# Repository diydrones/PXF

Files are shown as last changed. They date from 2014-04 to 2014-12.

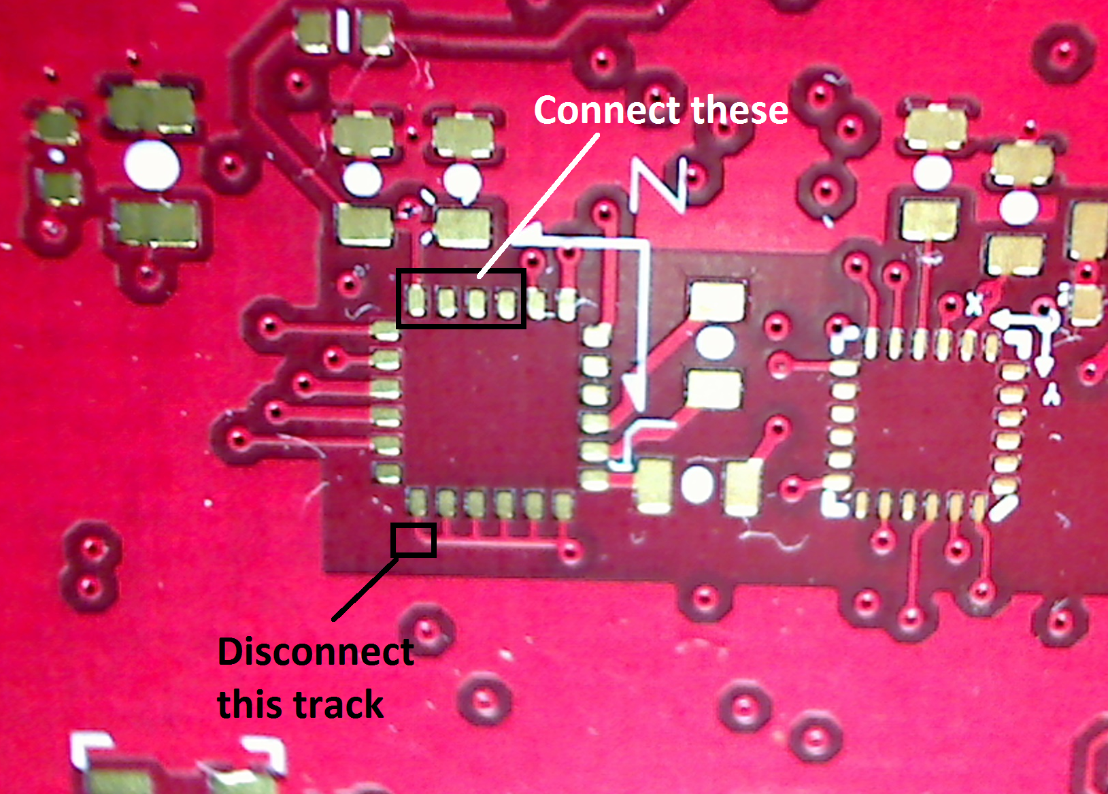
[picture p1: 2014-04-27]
v1.0 errata/LSM.png

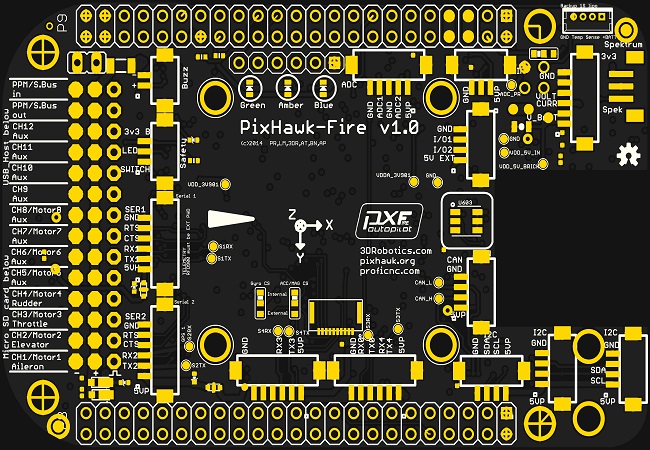
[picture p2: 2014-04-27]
CapeRegistration/PixHawk_Fire_v1.0_board_top.jpg

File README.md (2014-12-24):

PXF ( current boards are 1.4)
===


This is the new Repository for the PXF Linux AutoPilot. 

this Project will alow the porting of ArduPilot to Linux, allowing us to add a multitude of other features to the Autopilot.

The actual Autopilot code will still be in the ArduPilot repo.<a href="https://github.com/diydrones/ardupilot" title="https://github.com/diydrones/ardupilot" target="https://github.com/diydrones/ardupilot"> https://github.com/diydrones/ardupilot</a>

This Repo will house the Hardware Schematics, Datasheets, and software specific to the PXF project.

Version 1 of this project is a cape for the BBB.

This project is for developers, it will NOT be supported by the DIYDrones or Ardupilot support forums for general users. 

This means we do not expect that this board will be plug and play, nor do we intend it to be.

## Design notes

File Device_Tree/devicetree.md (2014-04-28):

Each cape for the BeagleBone Black has it's own **device tree fragment** as a overlay to the existing device tree.   
The **lib/firmware** consists of all the possible *overlays*

```
am335x-pm-firmware.bin		    BB-BONE-BACON-00A0.dtbo	BB-I2C1A1-00A0.dtbo	  cape-bone-2g-emmc1.dtbo	    libertas_cs_helper.fw
am33xx_pwm-00A0.dtbo		    BB-BONE-BACONE-00A0.dtbo	BB-SPIDEV0-00A0.dtbo	  cape-bone-adafruit-lcd-00A0.dtbo  LICENCE.atheros_firmware
atmel_at76c502_3com.bin		    BB-BONE-BACONE2-00A0.dtbo	BB-SPIDEV1-00A0.dtbo	  cape-boneblack-hdmi-00A0.dtbo     LICENCE.broadcom_bcm43xx
atmel_at76c502_3com-wpa.bin	    BB-BONE-CAM3-01-00A2.dtbo	BB-SPIDEV1A1-00A0.dtbo	  cape-boneblack-hdmin-00A0.dtbo    LICENCE.rtlwifi_firmware.txt
atmel_at76c502.bin		    BB-BONE-eMMC1-01-00A0.dtbo	BB-UART1-00A0.dtbo	  cape-bone-dvi-00A0.dtbo	    LICENCE.ti-connectivity
atmel_at76c502d.bin		    BB-BONE-GPEVT-00A0.dtbo	BB-UART2-00A0.dtbo	  cape-bone-dvi-00A1.dtbo	    mwl8k
atmel_at76c502d-wpa.bin		    BB-BONE-GPS-00A0.dtbo	BB-UART4-00A0.dtbo	  cape-bone-dvi-00A2.dtbo	    rt2561.bin
atmel_at76c502e.bin		    BB-BONE-LCD4-01-00A0.dtbo	BB-UART5-00A0.dtbo	  cape-bone-exptest-00A0.dtbo	    rt2561s.bin
atmel_at76c502e-wpa.bin		    BB-BONE-LCD4-01-00A1.dtbo	bone_pwm_P8_13-00A0.dtbo  cape-bone-geiger-00A0.dtbo	    rt2661.bin
atmel_at76c502-wpa.bin		    BB-BONE-LCD7-01-00A2.dtbo	bone_pwm_P8_19-00A0.dtbo  cape-bone-hexy-00A0.dtbo	    rt2860.bin
atmel_at76c503-i3861.bin	    BB-BONE-LCD7-01-00A3.dtbo	bone_pwm_P8_34-00A0.dtbo  cape-bone-iio-00A0.dtbo	    rt2870.bin
atmel_at76c503-i3863.bin	    BB-BONE-LCD7-01-00A4.dtbo	bone_pwm_P8_36-00A0.dtbo  cape-bone-lcd3-00A0.dtbo	    rt3070.bin
atmel_at76c503-rfmd-0.90.2-140.bin  BB-BONELT-BT-00A0.dtbo	bone_pwm_P8_45-00A0.dtbo  cape-bone-lcd3-00A2.dtbo	    rt3071.bin
atmel_at76c503-rfmd-acc.bin	    BB-BONE-PRU-01-00A0.dtbo	bone_pwm_P8_46-00A0.dtbo  cape-bone-mrf24j40-00A0.dtbo	    rt3090.bin
atmel_at76c503-rfmd.bin		    BB-BONE-PRU-02-00A0.dtbo	bone_pwm_P9_14-00A0.dtbo  cape-bone-nixie-00A0.dtbo	    rt73.bin
atmel_at76c504_2958-wpa.bin	    BB-BONE-PRU-03-00A0.dtbo	bone_pwm_P9_16-00A0.dtbo  cape-bone-pinmux-test-00A0.dtbo   rtlwifi
atmel_at76c504a_2958-wpa.bin	    BB-BONE-PRU-04-00A0.dtbo	bone_pwm_P9_21-00A0.dtbo  cape-bone-replicape-00A2.dtbo     sd8385.bin
atmel_at76c504.bin		    BB-BONE-PWMT-00A0.dtbo	bone_pwm_P9_22-00A0.dtbo  cape-bone-replicape-00A3.dtbo     sd8385_helper.bin
atmel_at76c504c-wpa.bin		    BB-BONE-RS232-00A0.dtbo	bone_pwm_P9_28-00A0.dtbo  cape-bone-tester-00A0.dtbo	    sd8686.bin
atmel_at76c505a-rfmd2958.bin	    BB-BONE-RST-00A0.dtbo	bone_pwm_P9_29-00A0.dtbo  cape-bone-weather-00A0.dtbo	    sd8686_helper.bin
atmel_at76c505-rfmd2958.bin	    BB-BONE-RST2-00A0.dtbo	bone_pwm_P9_31-00A0.dtbo  carl9170-1.fw			    sd8688.bin
atmel_at76c505-rfmd.bin		    BB-BONE-RTC-00A0.dtbo	bone_pwm_P9_42-00A0.dtbo  DNIL-AMPCAPE-1-00R1.dtbo	    sd8688_helper.bin
atmel_at76c506.bin		    BB-BONE-SERL-01-00A1.dtbo	brcm			  htc_9271.fw			    ti-connectivity
atmel_at76c506-wpa.bin		    BB-BONE-SERL-03-00A1.dtbo	cape-bebopr-brdg-R2.dtbo  lbtf_usb.bin			    TT3201-001-01.dtbo
BB-ADC-00A0.dtbo		    BB-GPIOHELP-00A0.dtbo	cape-bebopr-ena-R2.dtbo   libertas			    usb8388.bin
BB-BONE-AUDI-01-00A0.dtbo	    BB-I2C1-00A0.dtbo		cape-bebopr-R2.dtbo	  libertas_cs.fw		    zd1211
```
Capemgr is used to detect installed expansion boards and load the appropriate device tree fragment at boot time.  
> A key feature of Capemgr is the ability to load Device Tree fragments as overlays to the existing Device Tree at runtime. On the BeagleBone, each cape has a Device Tree fragment which describes it.

In the beagleboard kernel, for the PixHawk Fire cape, a patch file named will have to be merged [here](https://github.com/beagleboard/kernel/tree/3.8/patches/capes).

```
/*
* Copyright (C) 2014 Anuj Deshpande	<anujdeshpande92@gmail.com>
*
* This overlay enables 
*
* This program is free software; you can redistribute it and/or modify
* it under the terms of the GNU General Public License version 3 as
* published by the Free Software Foundation.
*/

/dts-v1/;
/plugin/;

/{
	compatible = "ti,beaglebone","ti,beaglebone-black" ;

	/* identification */
	part-number = "cape-bone-pxf";
	version = "00A0" ;

	/* state the resources this cape uses */
	exclusive-use =
		/* the pin header uses */
		"uart4",
		"uart5" ;

	fragment@0 {
		target = <&am33xx_pinmux>;
		__overlay__ {
			bb_uart4_pins: pinmux_bb_uart1_pins {
				pinctrl-single,pins = <0x70 0x26 0x74 0x06>;
			};
			bb_uart5_pins: pinmux_bb_uart4_pins {
				pinctrl-single,pins = ;
			};

```

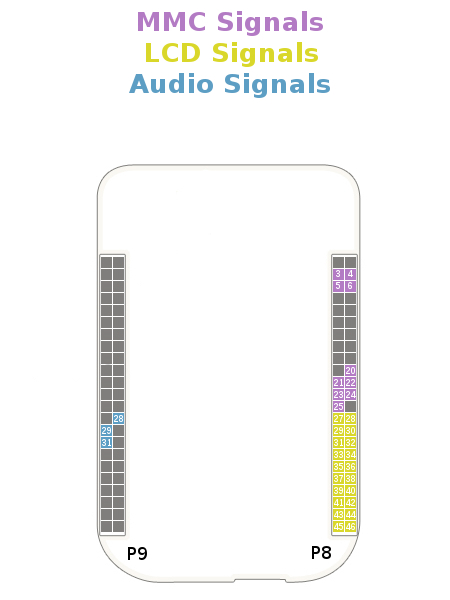
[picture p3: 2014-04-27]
Datasheet/Bbb-cape-pinout (1).jpg

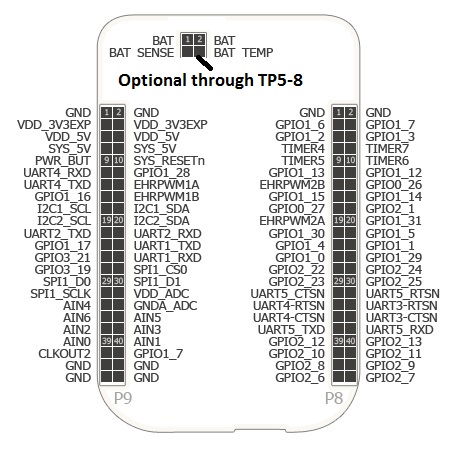
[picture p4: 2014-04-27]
CapeRegistration/PinDiagram.jpg

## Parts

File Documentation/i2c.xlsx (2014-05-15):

Device type | connected to bus number | part number | link to datasheet | ID on Schematic | I2C addresses BIN | other options
Onboard Beaglebone Eeprom | 2 | 24LC32A | http://ww1.microchip.com/downloads/en/DeviceDoc/21713H.pdf | BBB | 10101xxR | 0x54-0x57h
Cape ID EEPROM | 2 | AT24CS32 | http://www.atmel.com/Images/Atmel-8869-SEEPROM-AT24CS32-Datasheet.pdf | U1 | 1010100R | 0x54h
 |  |  | onboard serial number from eeprom | U1-B | 1011100R | 0x5Ch
Crypto EEPROM | 2 | ATSHA204 | http://www.atmel.com/Images/Atmel-8740-CryptoAuth-ATSHA204-Datasheet.pdf | U2 | 1100100R | 0x64h
Air preassure sensor | 2 | MS5611-01BA | http://www.meas-spec.com/downloads/MS5611-01BA03.pdf | U402 | 1110110R | 0x76h
LED Driver | 2 | TCA62724 | http://www.datasheetarchive.com/dlmain/Datasheets-SFU3/DSASFU100040579.pdf | U601 | 1010101R | 0x55h
Airspeed Sensor 1 | 2 | MS4525DO-DS3AIXXXDS | http://meas-spec.com/downloads/MS4525DO.pdf | External | 0101001R | 0x28h
Airspeed Sensor 2 | 2 | MS4525DO-DS3AJXXXDS | http://meas-spec.com/downloads/MS4525DO.pdf | External | 0110110R | 0x36h | 0x46,0x48H-0x51H
External compass | 2 | HMC5883L | http://www51.honeywell.com/aero/common/documents/myaerospacecatalog-documents/Defense_Brochures-documents/HMC5883L_3-Axis_Digital_Compass_IC.pdf | External | 0011110R | 0x1eh
Power management | 0 | TPS65217C | http://www.ti.com/lit/ds/symlink/tps65217c.pdf | BBB | 0100100R | 0x24h
unknown | 0 | onboard EEPROM |  | BBB | 1010000R | 0x50h
unknown | 0 | HDMI core in TDA19988 HDMI | http://hipstercircuits.com/wp-content/uploads/2013/05/TDA19988.pdf | BBB | 0110100R | 0x34h
unknown | 0 | CEC core in TDA19988 HDMI | http://hipstercircuits.com/wp-content/uploads/2013/05/TDA19988.pdf | BBB | 1110000R | 0x70h
old I2c board | 2 | HMC5883L | http://www51.honeywell.com/aero/common/documents/myaerospacecatalog-documents/Defense_Brochures-documents/HMC5883L_3-Axis_Digital_Compass_IC.pdf | old I2c board | 0011110R | 0x1eh
old I2c board | 2 | ADXL345 | http://www.analog.com/static/imported-files/data_sheets/ADXL345.pdf | old I2c board | 1010011R | 0x53h
old I2c board | 2 | L3G4200D | http://www.st.com/st-web-ui/static/active/en/resource/technical/document/datasheet/CD00265057.pdf | old I2c board | 1101001R | 0x69h
old I2c board | 2 | BMP085 | https://www.sparkfun.com/datasheets/Components/General/BST-BMP085-DS000-05.pdf | old I2c board | 1110111R | 0x77h

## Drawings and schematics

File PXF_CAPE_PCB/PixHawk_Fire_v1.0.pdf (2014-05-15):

15/05/2014 5:45:17 PM F:\Current_Work\00_0_git\PXF\PXF_CAPE_PCB\PixHawk_Fire_v1.0.sch (Sheet: 1/9)

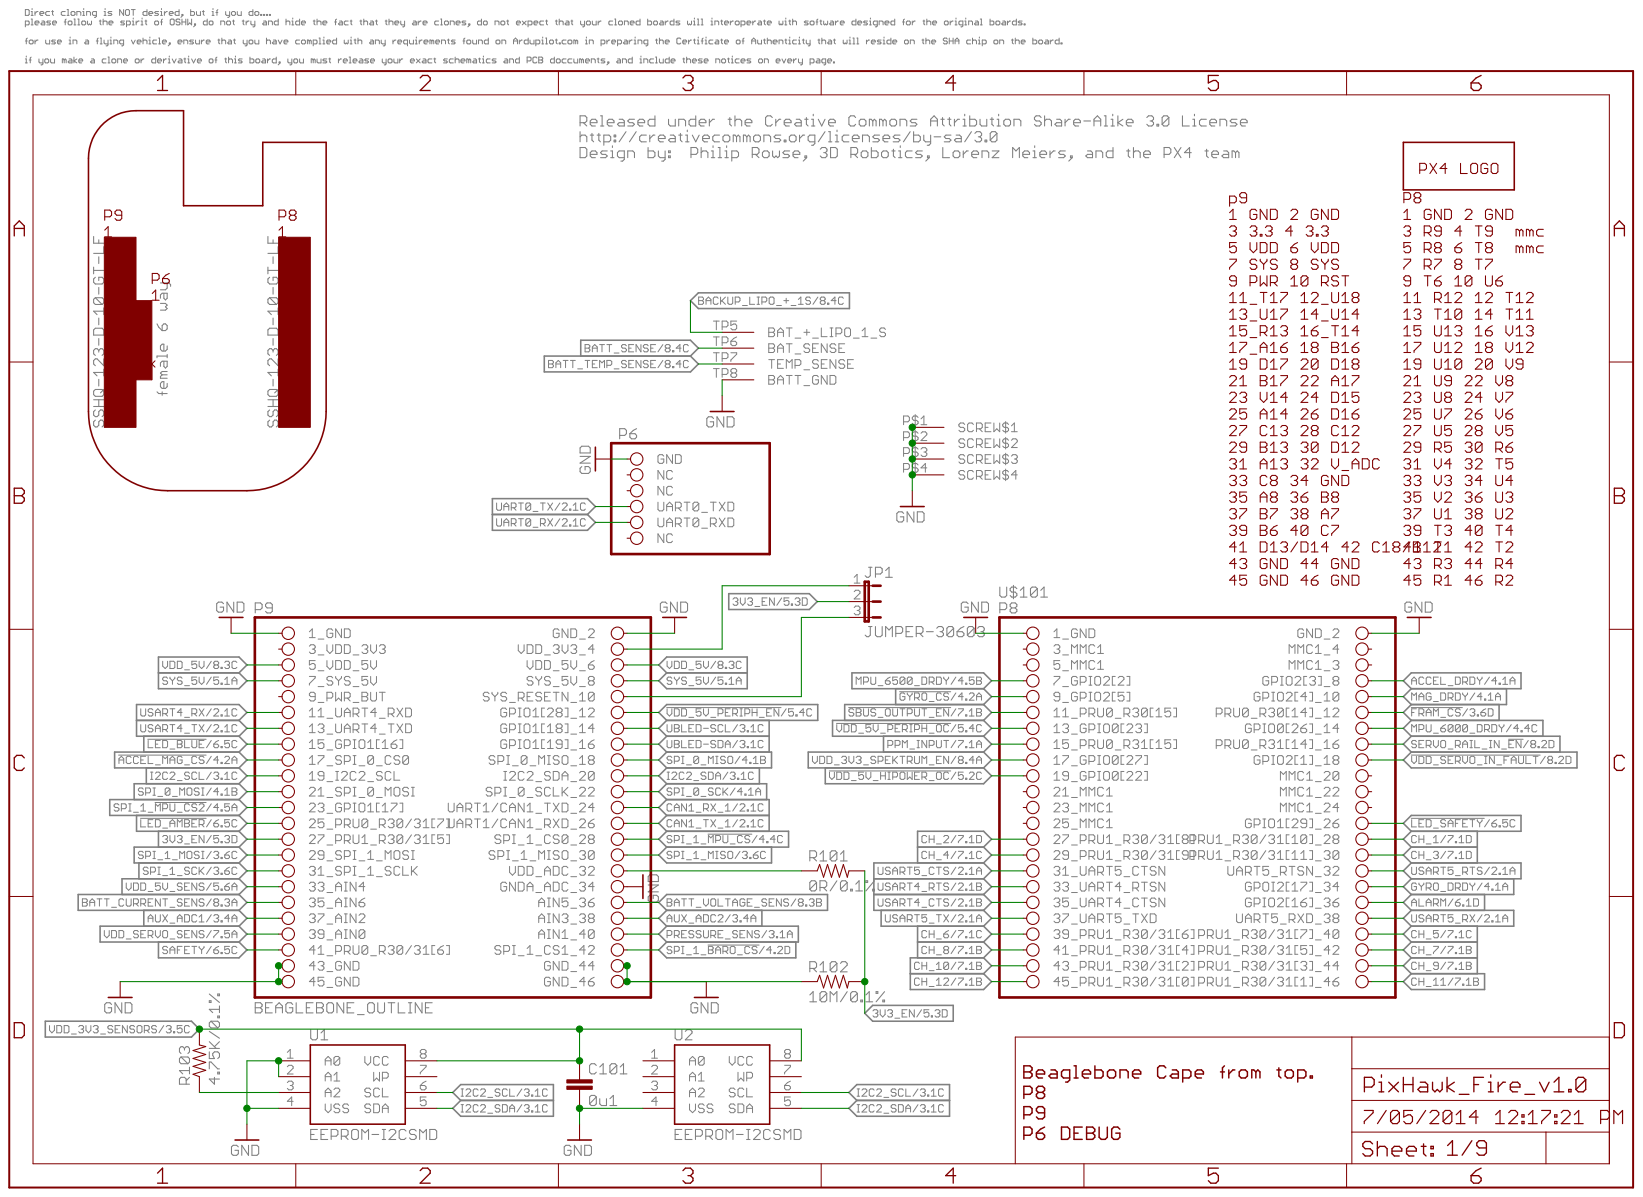
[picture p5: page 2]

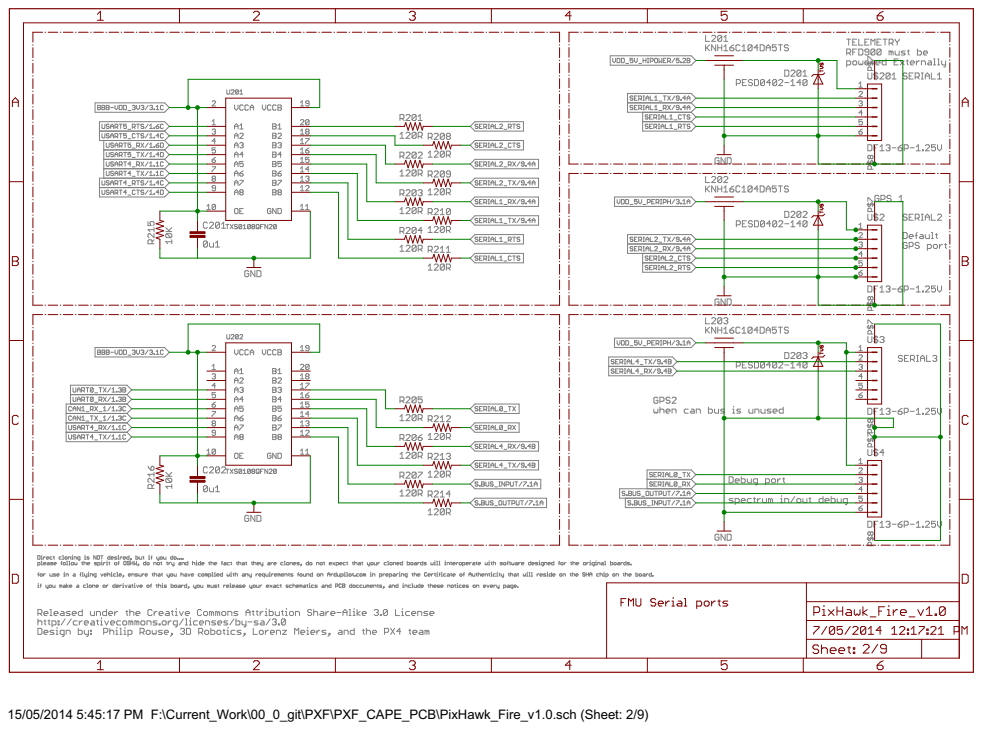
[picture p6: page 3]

15/05/2014 5:45:17 PM F:\Current_Work\00_0_git\PXF\PXF_CAPE_PCB\PixHawk_Fire_v1.0.sch (Sheet: 2/9)

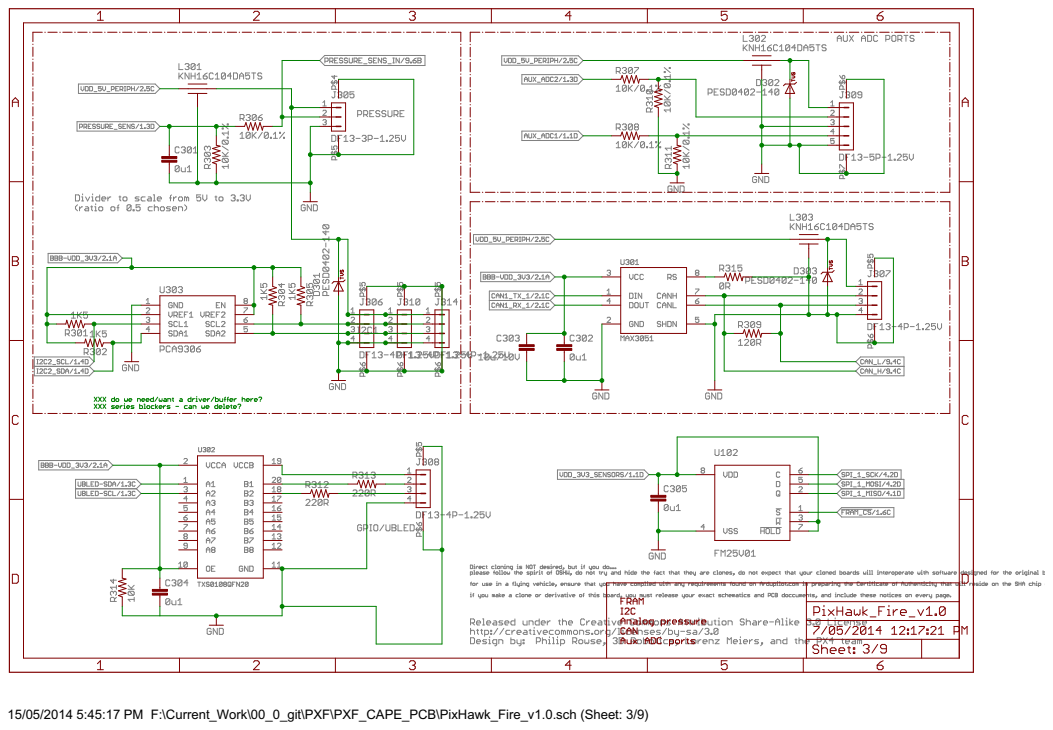
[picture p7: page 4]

15/05/2014 5:45:17 PM F:\Current_Work\00_0_git\PXF\PXF_CAPE_PCB\PixHawk_Fire_v1.0.sch (Sheet: 3/9)

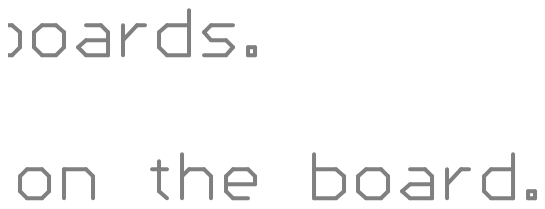
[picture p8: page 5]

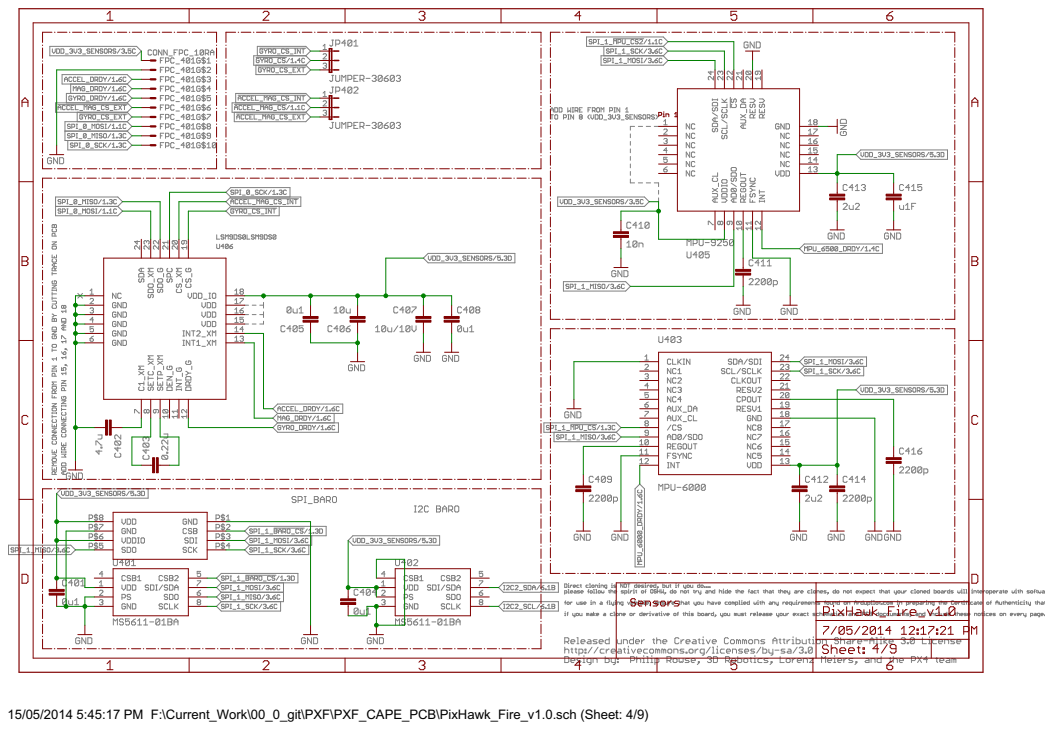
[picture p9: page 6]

15/05/2014 5:45:17 PM F:\Current_Work\00_0_git\PXF\PXF_CAPE_PCB\PixHawk_Fire_v1.0.sch (Sheet: 4/9)

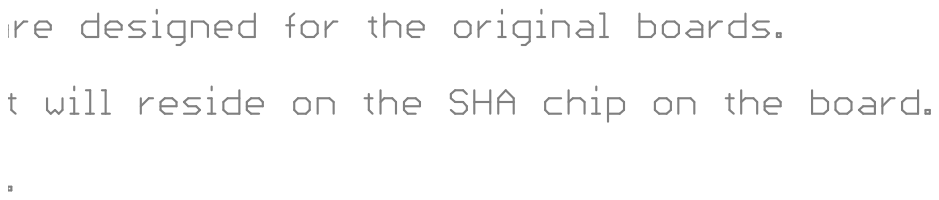
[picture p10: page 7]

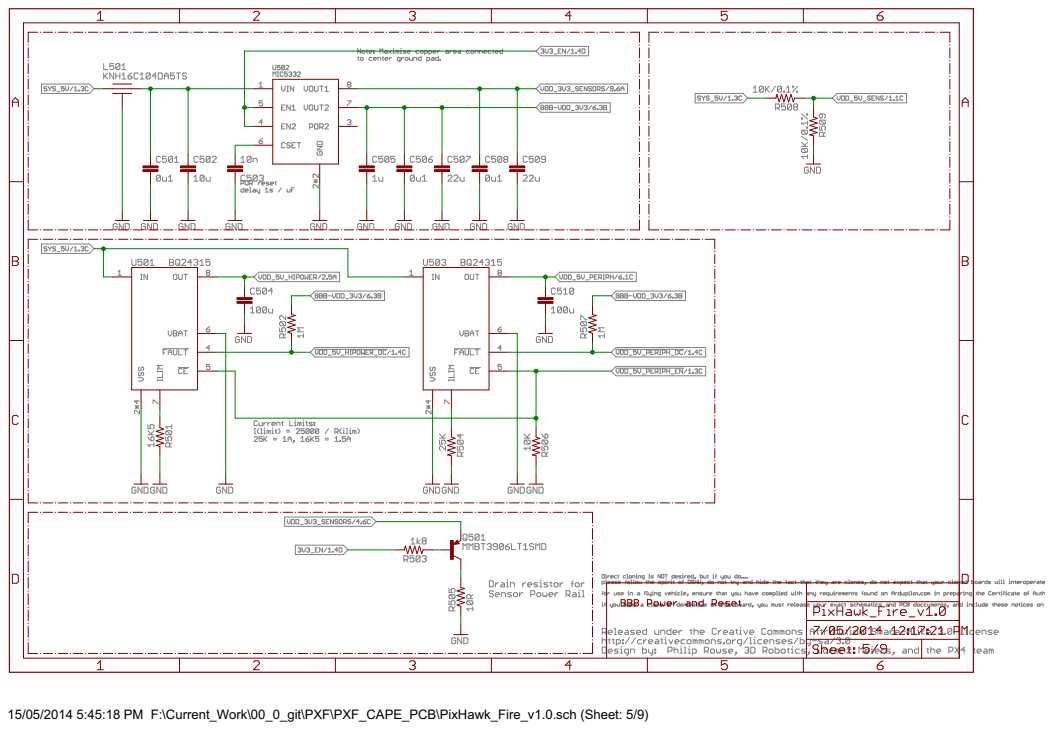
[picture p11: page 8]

15/05/2014 5:45:18 PM F:\Current_Work\00_0_git\PXF\PXF_CAPE_PCB\PixHawk_Fire_v1.0.sch (Sheet: 5/9)

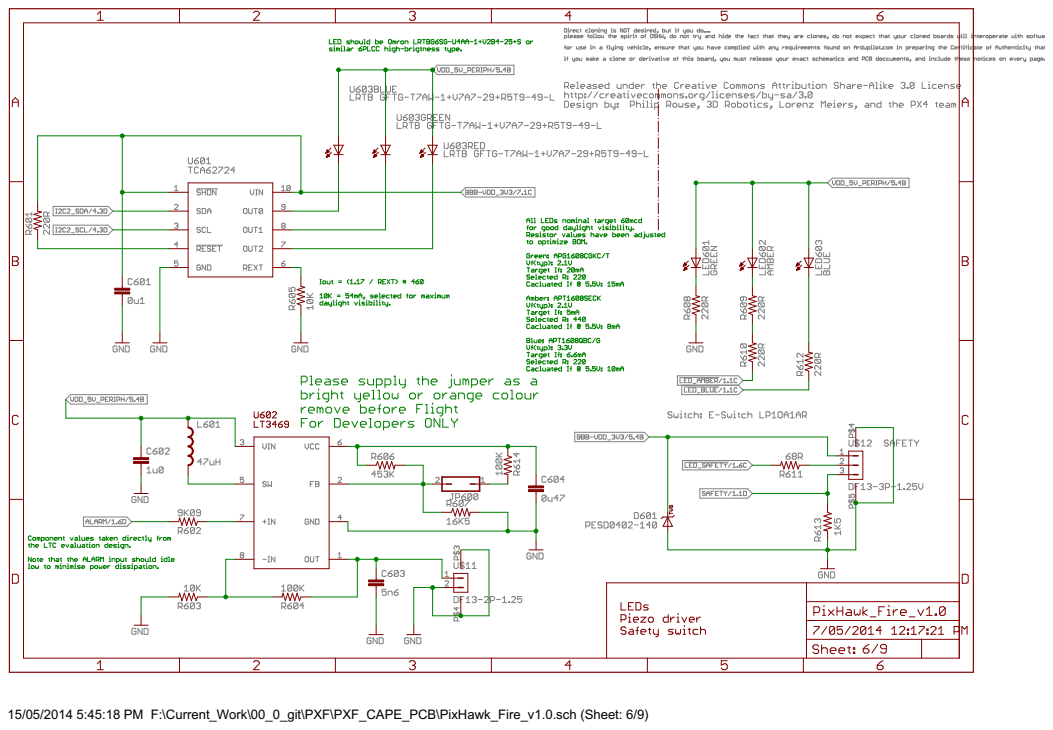
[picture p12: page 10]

15/05/2014 5:45:18 PM F:\Current_Work\00_0_git\PXF\PXF_CAPE_PCB\PixHawk_Fire_v1.0.sch (Sheet: 6/9)

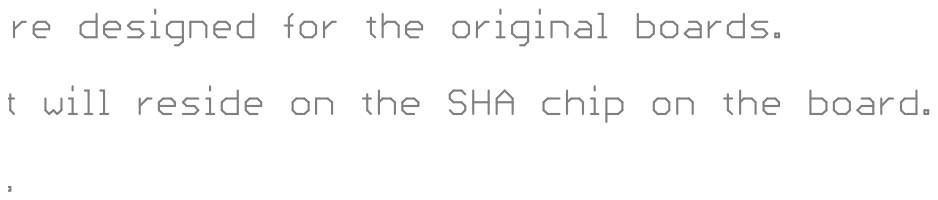
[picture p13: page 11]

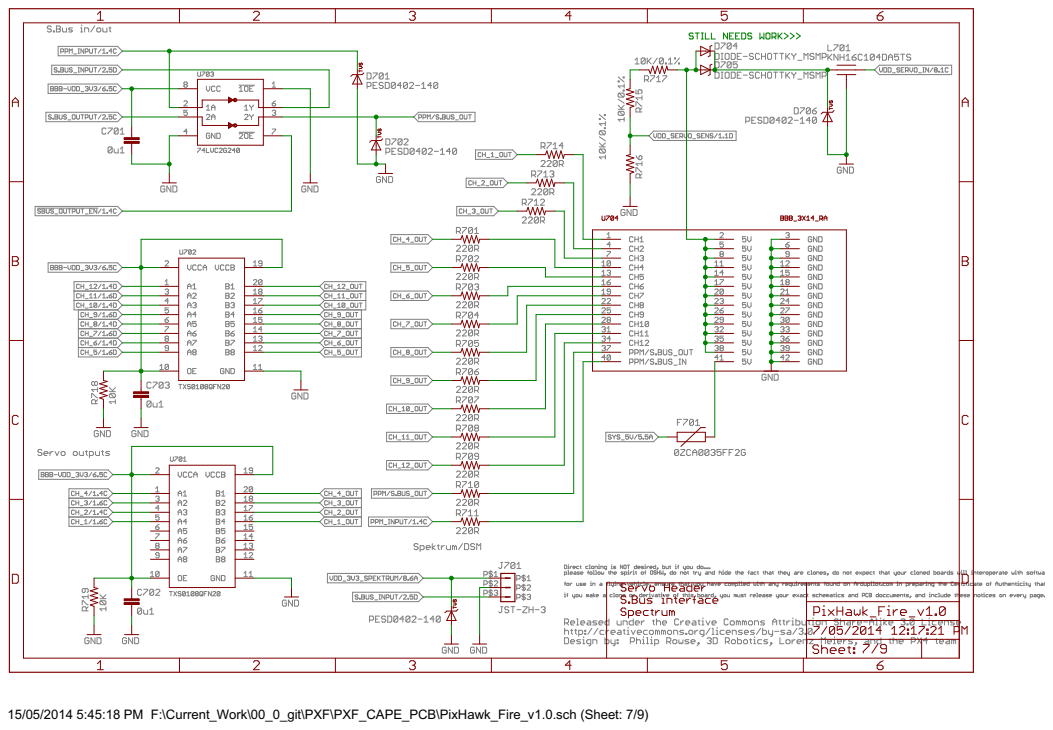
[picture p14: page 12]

15/05/2014 5:45:18 PM F:\Current_Work\00_0_git\PXF\PXF_CAPE_PCB\PixHawk_Fire_v1.0.sch (Sheet: 7/9)

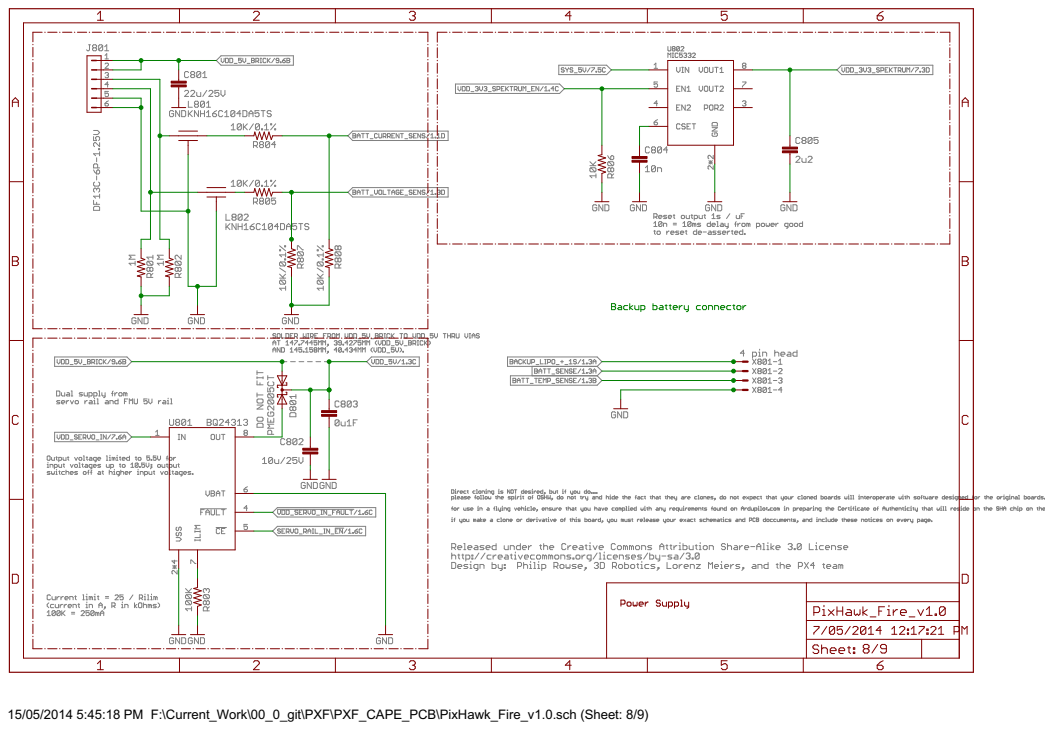
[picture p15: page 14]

15/05/2014 5:45:18 PM F:\Current_Work\00_0_git\PXF\PXF_CAPE_PCB\PixHawk_Fire_v1.0.sch (Sheet: 8/9)

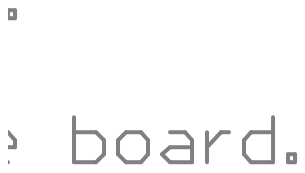
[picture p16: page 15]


15/05/2014 5:45:18 PM F:\Current_Work\00_0_git\PXF\PXF_CAPE_PCB\PixHawk_Fire_v1.0.sch (Sheet: 9/9)


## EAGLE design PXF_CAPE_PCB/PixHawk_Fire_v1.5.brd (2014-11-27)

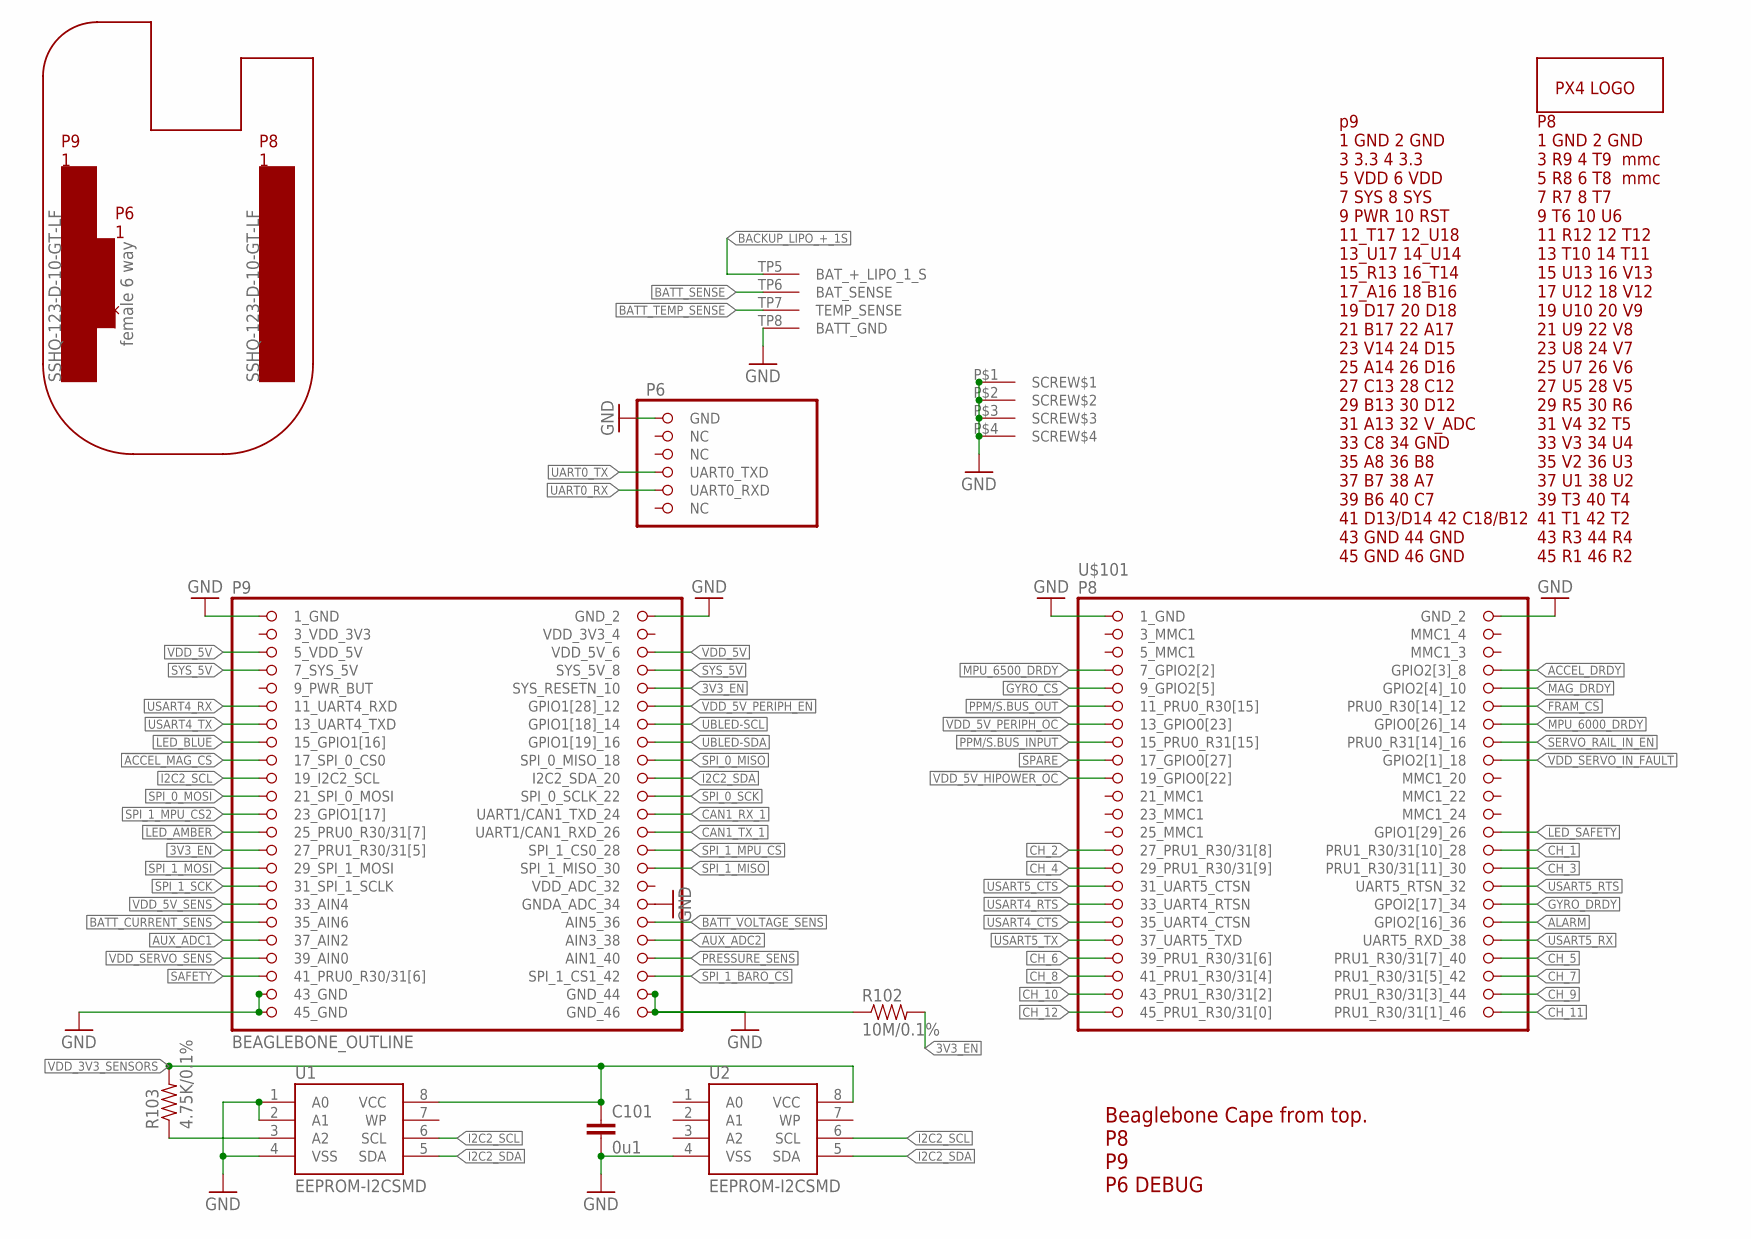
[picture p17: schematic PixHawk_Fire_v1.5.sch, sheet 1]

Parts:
C101: 0u1; 0402-CAP; PARTNO CC0402ZRY5V7BB104
R102: 10M/0.1%; 0402-RES; PARTNO RC0402FR-0710ML
R103: 4.75K/0.1%; 0402-RES; PARTNO RC0402FR-074K75L
U1: EEPROM-I2CSMD; SO08; PARTNO AT24CS32-SSHM
U2: EEPROM-I2CSMD; SO08; PARTNO ATSHA204-SH-DA-TTR-ND
U$1: PX4-LOGO; PIXHAWK-FIRE-LOGO-30
U$101: BEAGLEBONE_OUTLINE; BEAGLEBONE_SHIELD

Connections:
3V3_EN: R102.P$2 (2), U$101.56 (SYS_RESETN_10), U$101.73 (27_PRU1_R30/31[5]); also elsewhere on the board
3_VDD_3V3: U$101.49 (3_VDD_3V3)
!ACCEL_MAG_CS: U$101.63 (17_SPI_0_CS0); also elsewhere on the board
!FRAM_CS: U$101.12 (PRU0_R30[14]_12); also elsewhere on the board
!GYRO_CS: U$101.9 (9_GPIO2[5]); also elsewhere on the board
!LED_AMBER: U$101.71 (25_PRU0_R30/31[7]); also elsewhere on the board
!LED_BLUE: U$101.61 (15_GPIO1[16]); also elsewhere on the board
!LED_SAFETY: U$101.26 (GPIO1[29]_26); also elsewhere on the board
!VDD_5V_HIPOWER_OC: U$101.19 (19_GPIO0[22]); also elsewhere on the board
!VDD_5V_PERIPH_EN: U$101.58 (GPIO1[28]_12); also elsewhere on the board
!VDD_5V_PERIPH_OC: U$101.13 (13_GPIO0[23]); also elsewhere on the board
!VDD_SERVO_IN_FAULT: U$101.18 (GPIO2[1]_18)
ACCEL_DRDY: U$101.8 (GPIO2[3]_8); also elsewhere on the board
ALARM: U$101.36 (GPIO2[16]_36); also elsewhere on the board
AUX_ADC1: U$101.83 (37_AIN2); also elsewhere on the board
AUX_ADC2: U$101.84 (AIN3_38); also elsewhere on the board
BACKUP_LIPO_+_1S: U$101.TP5 (BAT_+_LIPO_1_S); also elsewhere on the board
BATT_CURRENT_SENS: U$101.81 (35_AIN6); also elsewhere on the board
BATT_SENSE: U$101.TP6 (BAT_SENSE); also elsewhere on the board
BATT_TEMP_SENSE: U$101.TP7 (TEMP_SENSE); also elsewhere on the board
BATT_VOLTAGE_SENS: U$101.82 (AIN5_36); also elsewhere on the board
CAN1_RX_1: U$101.70 (UART1/CAN1_TXD_24); also elsewhere on the board
CAN1_TX_1: U$101.72 (UART1/CAN1_RXD_26); also elsewhere on the board
CH_1: U$101.28 (PRU1_R30/31[10]_28); also elsewhere on the board
CH_2: U$101.27 (27_PRU1_R30/31[8]); also elsewhere on the board
CH_3: U$101.30 (PRU1_R30/31[11]_30); also elsewhere on the board
CH_4: U$101.29 (29_PRU1_R30/31[9]); also elsewhere on the board
CH_5: U$101.40 (PRU1_R30/31[7]_40); also elsewhere on the board
CH_6: U$101.39 (39_PRU1_R30/31[6]); also elsewhere on the board
CH_7: U$101.42 (PRU1_R30/31[5]_42); also elsewhere on the board
CH_8: U$101.41 (41_PRU1_R30/31[4]); also elsewhere on the board
CH_9: U$101.44 (PRU1_R30/31[3]_44); also elsewhere on the board
CH_10: U$101.43 (43_PRU1_R30/31[2]); also elsewhere on the board
CH_11: U$101.46 (PRU1_R30/31[1]_46); also elsewhere on the board
CH_12: U$101.45 (45_PRU1_R30/31[0]); also elsewhere on the board
GND: C101.P$2 (2), R102.P$1 (1), U1.1 (A0), U1.2 (A1), U1.4 (VSS), U2.4 (VSS), U$101.1 (1_GND), U$101.2 (GND_2), U$101.47 (1_GND), U$101.48 (GND_2), U$101.80 (GNDA_ADC_34), U$101.89 (43_GND), U$101.90 (GND_44), U$101.91 (45_GND), U$101.92 (GND_46), U$101.93 (GND), U$101.P$1 (SCREW$1), U$101.P$2 (SCREW$2), U$101.P$3 (SCREW$3), U$101.P$4 (SCREW$4), U$101.TP8 (BATT_GND); also elsewhere on the board
GYRO_DRDY: U$101.34 (GPOI2[17]_34); also elsewhere on the board
I2C2_SCL: U1.6 (SCL), U2.6 (SCL), U$101.65 (19_I2C2_SCL); also elsewhere on the board
I2C2_SDA: U1.5 (SDA), U2.5 (SDA), U$101.66 (I2C2_SDA_20); also elsewhere on the board
MAG_DRDY: U$101.10 (GPIO2[4]_10); also elsewhere on the board
MPU_6000_DRDY: U$101.14 (GPIO0[26]_14); also elsewhere on the board
MPU_6500_DRDY: U$101.7 (7_GPIO2[2]); also elsewhere on the board
unnamed: R103.P$1 (1), U1.3 (A2)
PPM/S.BUS_INPUT: U$101.15 (15_PRU0_R31[15]); also elsewhere on the board
PPM/S.BUS_OUT: U$101.11 (11_PRU0_R30[15]); also elsewhere on the board
PRESSURE_SENS: U$101.86 (AIN1_40); also elsewhere on the board
SAFETY: U$101.87 (41_PRU0_R30/31[6]); also elsewhere on the board
SERVO_RAIL_IN_!EN: U$101.16 (PRU0_R31[14]_16)
SPARE: U$101.17 (17_GPIO0[27])
SPI_0_MISO: U$101.64 (SPI_0_MISO_18); also elsewhere on the board
SPI_0_MOSI: U$101.67 (21_SPI_0_MOSI); also elsewhere on the board
SPI_0_SCK: U$101.68 (SPI_0_SCLK_22); also elsewhere on the board
SPI_1_!BARO_CS: U$101.88 (SPI_1_CS1_42); also elsewhere on the board
SPI_1_!MPU_CS: U$101.74 (SPI_1_CS0_28); also elsewhere on the board
SPI_1_!MPU_CS2: U$101.69 (23_GPIO1[17]); also elsewhere on the board
SPI_1_MISO: U$101.76 (SPI_1_MISO_30); also elsewhere on the board
SPI_1_MOSI: U$101.75 (29_SPI_1_MOSI); also elsewhere on the board
SPI_1_SCK: U$101.77 (31_SPI_1_SCLK); also elsewhere on the board
SYS_5V: U$101.53 (7_SYS_5V), U$101.54 (SYS_5V_8); also elsewhere on the board
UART0_RX: U$101.97 (UART0_RXD); also elsewhere on the board
UART0_TX: U$101.96 (UART0_TXD); also elsewhere on the board
UBLED-SCL: U$101.60 (GPIO1[18]_14); also elsewhere on the board
UBLED-SDA: U$101.62 (GPIO1[19]_16); also elsewhere on the board
USART4_CTS: U$101.35 (35_UART4_CTSN); also elsewhere on the board
USART4_RTS: U$101.33 (33_UART4_RTSN); also elsewhere on the board
USART4_RX: U$101.57 (11_UART4_RXD); also elsewhere on the board
USART4_TX: U$101.59 (13_UART4_TXD); also elsewhere on the board
USART5_CTS: U$101.31 (31_UART5_CTSN); also elsewhere on the board
USART5_RTS: U$101.32 (UART5_RTSN_32); also elsewhere on the board
USART5_RX: U$101.38 (UART5_RXD_38); also elsewhere on the board
USART5_TX: U$101.37 (37_UART5_TXD); also elsewhere on the board
VDD_3V3_4: U$101.50 (VDD_3V3_4)
VDD_3V3_SENSORS: C101.P$1 (1), R103.P$2 (2), U1.8 (VCC), U2.8 (VCC); also elsewhere on the board
VDD_5V: U$101.51 (5_VDD_5V), U$101.52 (VDD_5V_6); also elsewhere on the board
VDD_5V_SENS: U$101.79 (33_AIN4); also elsewhere on the board
VDD_SERVO_SENS: U$101.85 (39_AIN0); also elsewhere on the board

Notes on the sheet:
Beaglebone Cape from top. P8 P9 P6 DEBUG

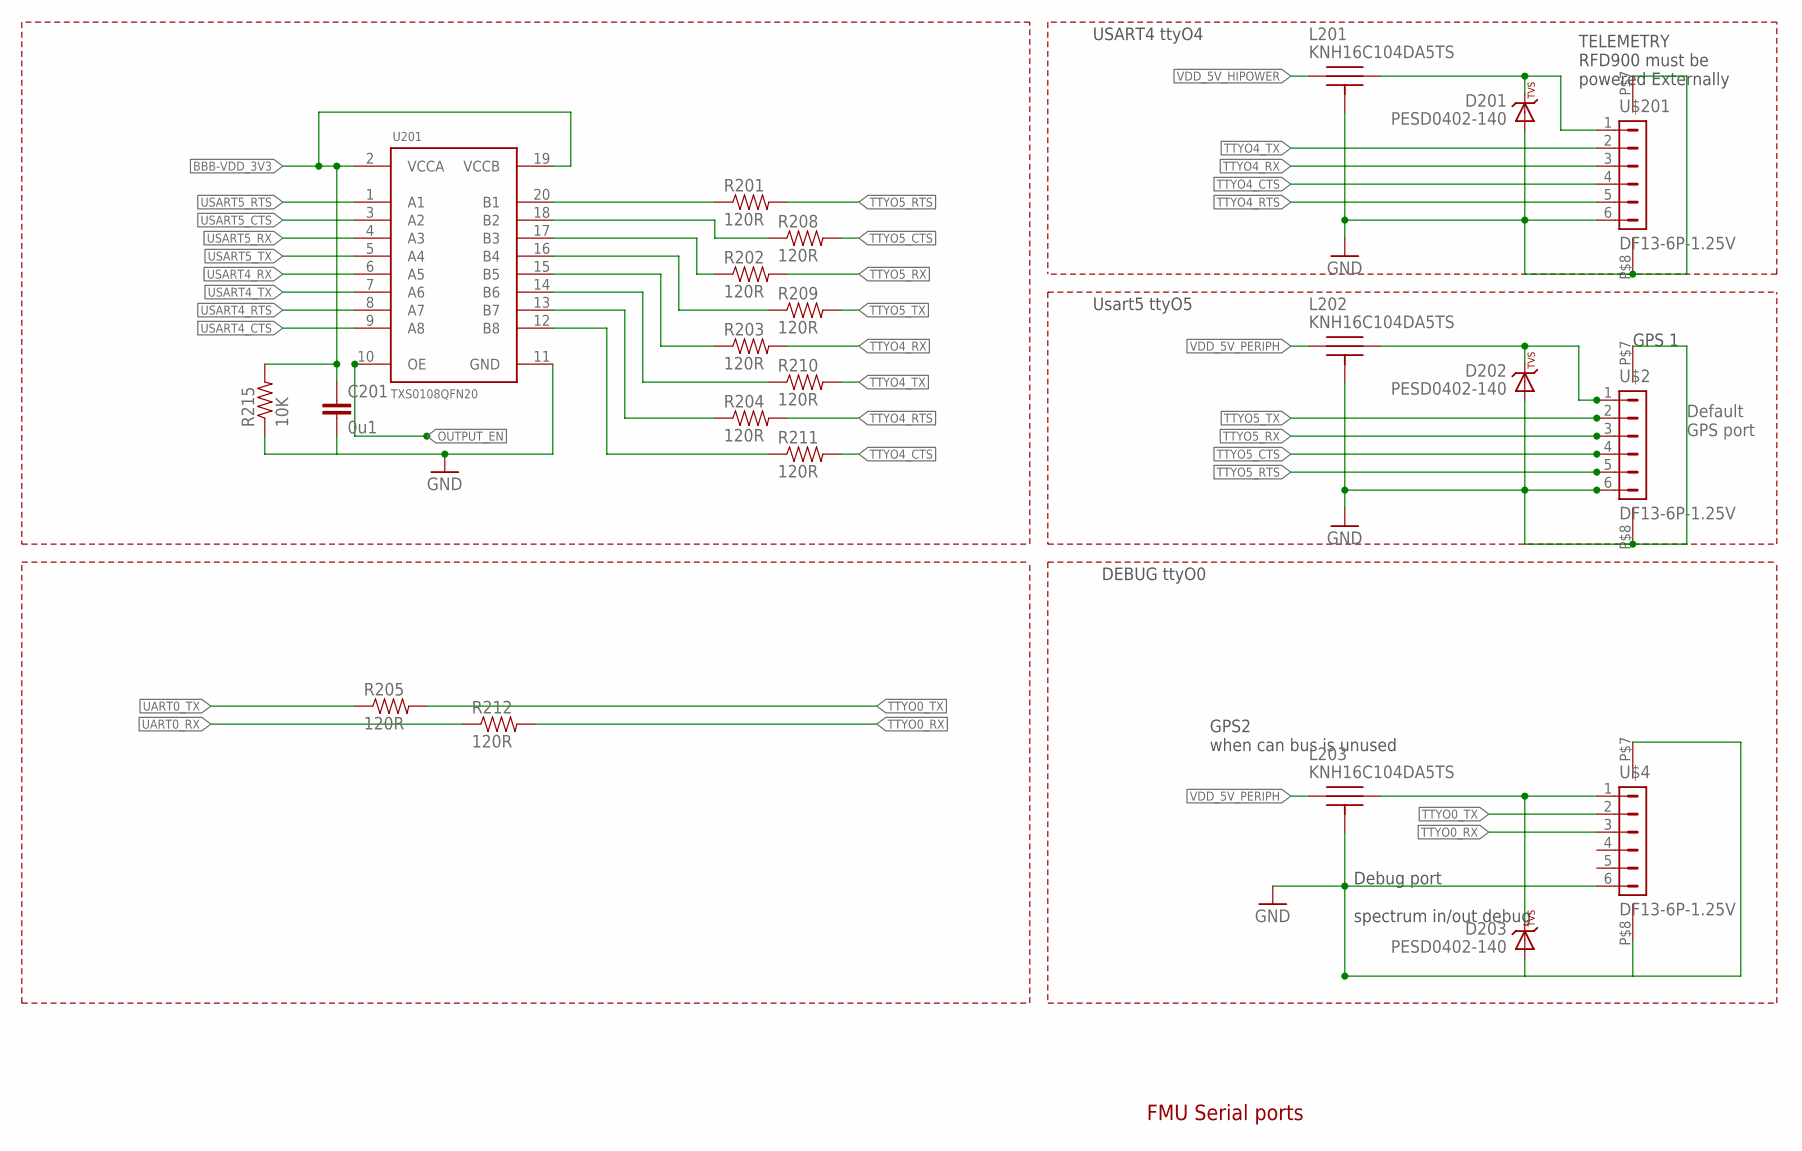
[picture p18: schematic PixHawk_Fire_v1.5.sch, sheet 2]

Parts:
C201: 0u1; 0402-CAP; PARTNO CC0402ZRY5V7BB104
D201, D202, D203: PESD0402-140; 0402-TVS; PARTNO PESD0402-140
L201, L202, L203: KNH16C104DA5TS; KYOCERA-KNH16-DA; PARTNO KNH16C104DA5TS
R201, R202, R203, R204, R205, R208, R209, R210, R211, R212: 120R; 0402-RES; PARTNO RC0402FR-07120RL
R215: 10K; 0402-RES; PARTNO ERA-2AEB103X
U201: TXS0108QFN20; QFN20-RGY; PARTNO TXS0108ERGYR
U$2, U$4, U$201: DF13-6P-1.25V; DF13C-6P-1.25V; PARTNO DF13C-6P-1.25V(20)

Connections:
BBB-VDD_3V3: C201.P$1 (1), R215.P$2 (2), U201.2 (VCCA), U201.19 (VCCB); also elsewhere on the board
GND: C201.P$2 (2), D201.A, D202.A, D203.A, L201.P$3, L201.P$4, L201.P$5, L202.P$3, L202.P$4, L202.P$5, L203.P$3, L203.P$4, L203.P$5, R215.P$1 (1), U201.11 (GND), U$2.6, U$2.P$7, U$2.P$8, U$4.6, U$4.P$7, U$4.P$8, U$201.6, U$201.P$7, U$201.P$8; also elsewhere on the board
unnamed: D201.C, L201.P$2, U$201.1
unnamed: R208.P$1 (1), U201.18 (B2)
unnamed: R201.P$1 (1), U201.20 (B1)
unnamed: R202.P$1 (1), U201.17 (B3)
unnamed: R209.P$1 (1), U201.16 (B4)
unnamed: R203.P$1 (1), U201.15 (B5)
unnamed: R210.P$1 (1), U201.14 (B6)
unnamed: R204.P$1 (1), U201.13 (B7)
unnamed: R211.P$1 (1), U201.12 (B8)
unnamed: D203.C, L203.P$2, U$4.1
unnamed: D202.C, L202.P$2, U$2.1
OUTPUT_EN: U201.10 (OE); also elsewhere on the board
TTYO0_RX: R212.P$2 (2), U$4.3
TTYO0_TX: R205.P$2 (2), U$4.2
TTYO4_CTS: R211.P$2 (2), U$201.4
TTYO4_RTS: R204.P$2 (2), U$201.5
TTYO4_RX: R203.P$2 (2), U$201.3; also elsewhere on the board
TTYO4_TX: R210.P$2 (2), U$201.2; also elsewhere on the board
TTYO5_CTS: R208.P$2 (2), U$2.4
TTYO5_RTS: R201.P$2 (2), U$2.5
TTYO5_RX: R202.P$2 (2), U$2.3; also elsewhere on the board
TTYO5_TX: R209.P$2 (2), U$2.2; also elsewhere on the board
UART0_RX: R212.P$1 (1); also elsewhere on the board
UART0_TX: R205.P$1 (1); also elsewhere on the board
USART4_CTS: U201.9 (A8); also elsewhere on the board
USART4_RTS: U201.8 (A7); also elsewhere on the board
USART4_RX: U201.6 (A5); also elsewhere on the board
USART4_TX: U201.7 (A6); also elsewhere on the board
USART5_CTS: U201.3 (A2); also elsewhere on the board
USART5_RTS: U201.1 (A1); also elsewhere on the board
USART5_RX: U201.4 (A3); also elsewhere on the board
USART5_TX: U201.5 (A4); also elsewhere on the board
VDD_5V_HIPOWER: L201.P$1; also elsewhere on the board
VDD_5V_PERIPH: L202.P$1, L203.P$1; also elsewhere on the board

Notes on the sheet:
FMU Serial ports
Usart5 ttyO5
USART4 ttyO4
DEBUG ttyO0
Default GPS port
TELEMETRY RFD900 must be powered Externally
GPS 1
Debug port spectrum in/out debug
GPS2 when can bus is unused

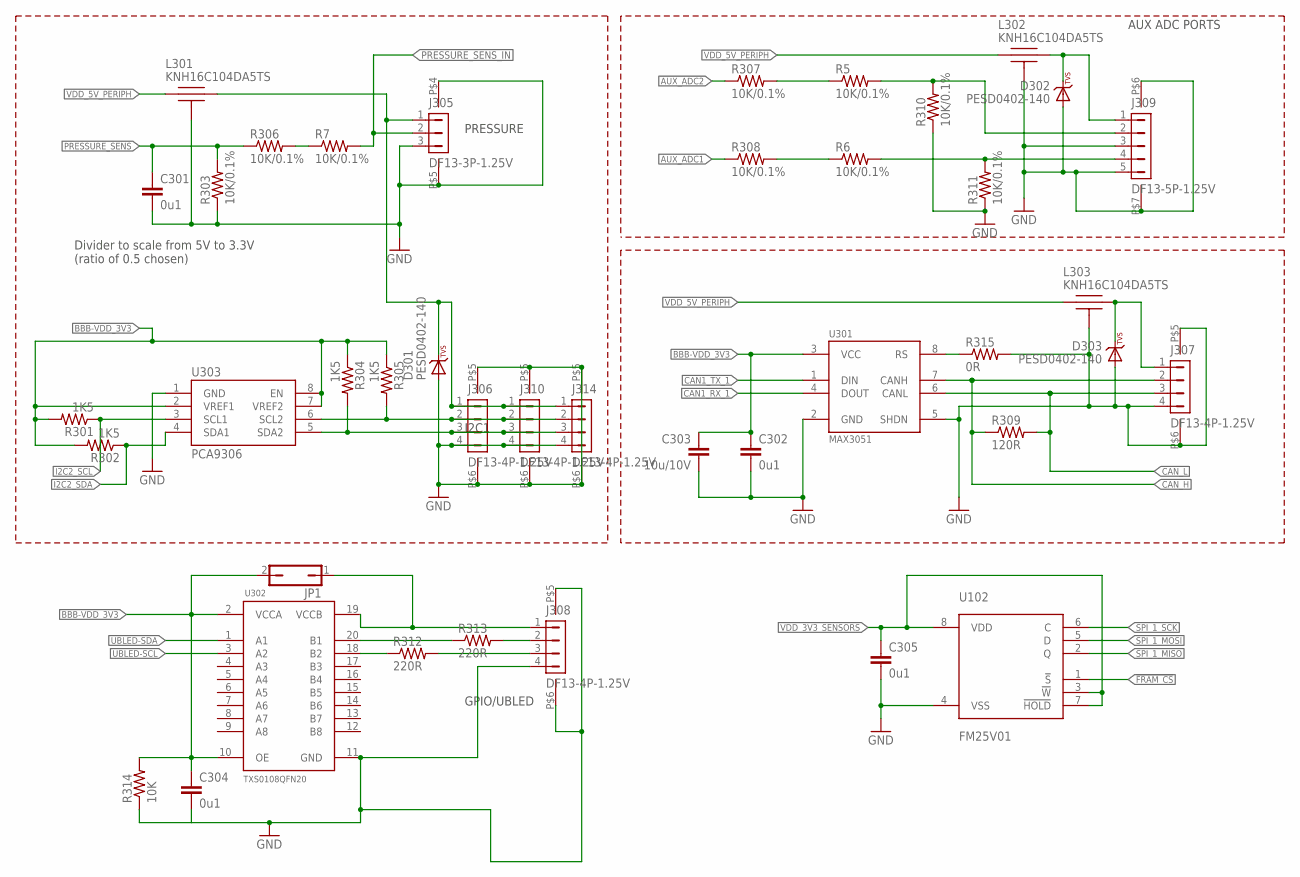
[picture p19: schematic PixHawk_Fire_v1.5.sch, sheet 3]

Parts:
C301, C302, C304, C305: 0u1; 0402-CAP; PARTNO CC0402ZRY5V7BB104
C303: 10u/10V; 0805-CAP; PARTNO CC0805ZKY5V6BB106
D301, D302, D303: PESD0402-140; 0402-TVS; PARTNO PESD0402-140
J305: DF13-3P-1.25V; DF13C-3P-1.25V; PARTNO DF13C-3P-1.25V(20)
J306, J307, J308, J310, J314: DF13-4P-1.25V; DF13C-4P-1.25V; PARTNO DF13C-4P-1.25V(20)
J309: DF13-5P-1.25V; DF13C-5P-1.25V; PARTNO DF13C-5P-1.25V(20)
JP1: JP1Q; JP1; PARTNO 1-87215-0
L301, L302, L303: KNH16C104DA5TS; KYOCERA-KNH16-DA; PARTNO KNH16C104DA5TS
R5, R6, R7, R303, R306, R307, R308, R310, R311: 10K/0.1%; 0402-RES; PARTNO ERA-2AEB103X
R301, R302, R304, R305: 1K5; 0402-RES; PARTNO RC0402FR-071K5L
R309: 120R; 0402-RES; PARTNO RC0402FR-07120RL
R312, R313: 220R; 0402-RES; PARTNO RC0402FR-07220RL
R314: 10K; 0402-RES; PARTNO ERA-2AEB103X
R315: 0R; 0402-RES; PARTNO RC0402FR-070RL
U102: FM25V01; SO08; PARTNO FM25V01-G
U301: MAX3051; SOT23-8; PARTNO MAX3051EKA
U302: TXS0108QFN20; QFN20-RGY; PARTNO TXS0108ERGYR
U303: PCA9306; PARTNO PCA9306DQER

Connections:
!FRAM_CS: U102.1 (!S); also elsewhere on the board
AUX_ADC1: R308.P$1 (1); also elsewhere on the board
AUX_ADC2: R307.P$1 (1); also elsewhere on the board
BBB-VDD_3V3: C302.P$1 (1), C303.P$1 (1), C304.P$1 (1), JP1.2, R301.P$2 (2), R302.P$2 (2), R304.P$1 (1), R305.P$1 (1), R314.P$2 (2), U301.3 (VCC), U302.2 (VCCA), U302.10 (OE), U303.2 (VREF1), U303.7 (VREF2), U303.8 (EN); also elsewhere on the board
CAN1_RX_1: U301.4 (DOUT); also elsewhere on the board
CAN1_TX_1: U301.1 (DIN); also elsewhere on the board
CAN_H: J307.2, R309.P$1 (1), U301.7 (CANH); also elsewhere on the board
CAN_L: J307.3, R309.P$2 (2), U301.6 (CANL); also elsewhere on the board
FMU_AUX_ADC1_PROT: J309.4, R6.P$2 (2), R311.P$2 (2)
FMU_AUX_ADC2_PROT: J309.2, R5.P$2 (2), R310.P$2 (2)
GND: C301.P$2 (2), C302.P$2 (2), C303.P$2 (2), C304.P$2 (2), C305.P$2 (2), D301.A, D302.A, D303.A, J305.3, J305.P$4, J305.P$5, J306.4, J306.P$5, J306.P$6, J307.4, J307.P$5, J307.P$6, J308.4, J308.P$5, J308.P$6, J309.3, J309.5, J309.P$6, J309.P$7, J310.4, J310.P$5, J310.P$6, J314.4, J314.P$5, J314.P$6, L301.P$3, L301.P$4, L301.P$5, L302.P$3, L302.P$4, L302.P$5, L303.P$3, L303.P$4, L303.P$5, R303.P$1 (1), R310.P$1 (1), R311.P$1 (1), R314.P$1 (1), R315.P$2 (2), U102.4 (VSS), U301.2 (GND), U301.5 (SHDN), U302.11 (GND), U303.1 (GND); also elsewhere on the board
I2C2_SCL: R301.P$1 (1), U303.3 (SCL1); also elsewhere on the board
I2C2_SDA: R302.P$1 (1), U303.4 (SDA1); also elsewhere on the board
unnamed: R313.P$1 (1), U302.20 (B1)
unnamed: J306.2, J310.2, J314.2, R305.P$2 (2), U303.6 (SCL2)
unnamed: J306.3, J310.3, J314.3, R304.P$2 (2), U303.5 (SDA2)
unnamed: R312.P$1 (1), U302.18 (B2)
unnamed: D301.C, J305.1, J306.1, J310.1, J314.1, L301.P$2
unnamed: J308.3, R312.P$2 (2)
unnamed: J308.2, R313.P$2 (2)
unnamed: J308.1, JP1.1, U302.19 (VCCB)
unnamed: D303.C, J307.1, L303.P$2
unnamed: R315.P$1 (1), U301.8 (RS)
unnamed: R5.P$1 (1), R307.P$2 (2)
unnamed: R6.P$1 (1), R308.P$2 (2)
unnamed: R7.P$1 (1), R306.P$2 (2)
unnamed: D302.C, J309.1, L302.P$2
PRESSURE_SENS: C301.P$1 (1), R303.P$2 (2), R306.P$1 (1); also elsewhere on the board
PRESSURE_SENS_IN: J305.2, R7.P$2 (2); also elsewhere on the board
SPI_1_MISO: U102.2 (Q); also elsewhere on the board
SPI_1_MOSI: U102.5 (D); also elsewhere on the board
SPI_1_SCK: U102.6 (C); also elsewhere on the board
UBLED-SCL: U302.3 (A2); also elsewhere on the board
UBLED-SDA: U302.1 (A1); also elsewhere on the board
VDD_3V3_SENSORS: C305.P$1 (1), U102.3 (!W), U102.7 (!HOLD), U102.8 (VDD); also elsewhere on the board
VDD_5V_PERIPH: L301.P$1, L302.P$1, L303.P$1; also elsewhere on the board

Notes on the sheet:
PRESSURE
I2C1
AUX ADC PORTS
Divider to scale from 5V to 3.3V (ratio of 0.5 chosen)
GPIO/UBLED

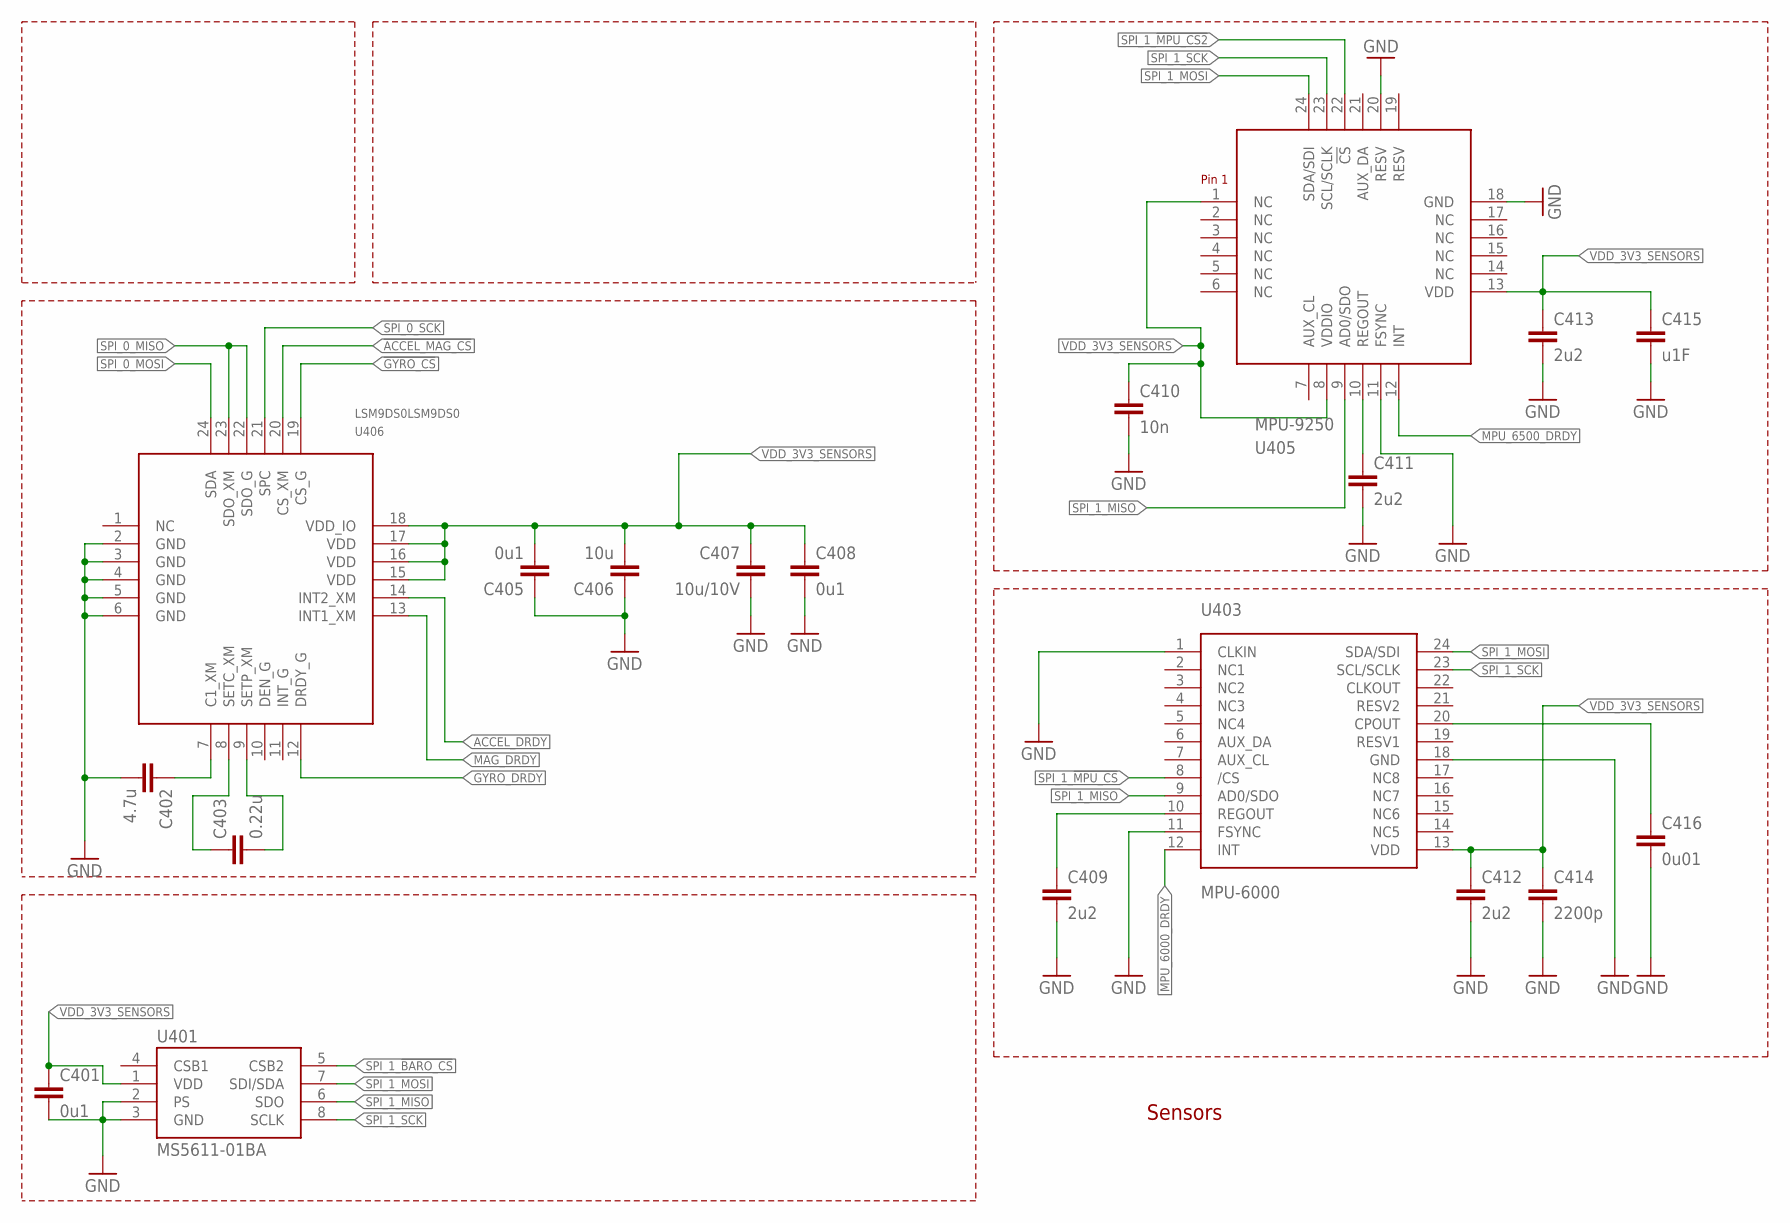
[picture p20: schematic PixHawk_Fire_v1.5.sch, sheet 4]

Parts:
C401, C408: 0u1; 0402-CAP; PARTNO CC0402ZRY5V7BB104
C402: 4.7u; 0603-CAP; PARTNO C1608X7S1A475K080AC
C403: 0.22u; 0603-CAP; PARTNO CL10B224JP8NNNC
C405: 0u1; 0603-CAP; PARTNO CL10B104JO8NNNC
C406: 10u; 0603-CAP; PARTNO C1608X7S0J106M080AC
C407: 10u/10V; 0805-CAP; PARTNO CC0805ZKY5V6BB106
C409, C411: 2u2; 0603-CAP; PARTNO C1608X6S1C225K080AC
C410: 10n; 0603-CAP; PARTNO C0603C103J5RAC7411
C412: 2u2; 0603-CAP; PARTNO CGA3E1X7R0J225K080AC
C413: 2u2; 0603-CAP
C414: 2200p; 0402-CAP; PARTNO C0603C222J5RACTU
C415: u1F; 0402-CAP; PARTNO CC0402ZRY5V7BB104
C416: 0u01; 0603-CAP; PARTNO 06033C103JAT2A
U401: MS5611-01BA; PARTNO MS5611-01BA
U403: MPU-6000; QFN-24; PARTNO MPU-6000
U405: MPU-9250; MPU-6500; PARTNO MPU-9250
U406: LSM9DS0LSM9DS0; LSM9DS0; PARTNO LSM9DS0TR

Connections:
!ACCEL_MAG_CS: U406.20 (CS_XM); also elsewhere on the board
!GYRO_CS: U406.19 (CS_G); also elsewhere on the board
ACCEL_DRDY: U406.14 (INT2_XM); also elsewhere on the board
GND: C401.P$2 (2), C402.P$2 (2), C405.P$1 (1), C406.P$1 (1), C407.P$2 (2), C408.P$2 (2), C409.P$2 (2), C410.P$2 (2), C411.P$2 (2), C412.P$2 (2), C413.P$2 (2), C414.P$2 (2), C415.P$2 (2), C416.P$2 (2), U401.2 (PS), U401.3 (GND), U403.1 (CLKIN), U403.11 (FSYNC), U403.18 (GND), U405.11 (FSYNC), U405.18 (GND), U405.20 (RESV), U406.2 (GND), U406.3 (GND), U406.4 (GND), U406.5 (GND), U406.6 (GND); also elsewhere on the board
GYRO_DRDY: U406.12 (DRDY_G); also elsewhere on the board
MAG_DRDY: U406.13 (INT1_XM); also elsewhere on the board
MPU_6000_DRDY: U403.12 (INT); also elsewhere on the board
MPU_6500_DRDY: U405.12 (INT); also elsewhere on the board
unnamed: C402.P$1 (1), U406.7 (C1_XM)
unnamed: C403.P$2 (2), U406.9 (SETP_XM)
unnamed: C411.P$1 (1), U405.10 (REGOUT)
unnamed: C403.P$1 (1), U406.8 (SETC_XM)
unnamed: C409.P$1 (1), U403.10 (REGOUT)
unnamed: C416.P$1 (1), U403.20 (CPOUT)
SPI_0_MISO: U406.22 (SDO_G), U406.23 (SDO_XM); also elsewhere on the board
SPI_0_MOSI: U406.24 (SDA); also elsewhere on the board
SPI_0_SCK: U406.21 (SPC); also elsewhere on the board
SPI_1_!BARO_CS: U401.5 (CSB2); also elsewhere on the board
SPI_1_!MPU_CS: U403.8 (/CS); also elsewhere on the board
SPI_1_!MPU_CS2: U405.22 (!CS); also elsewhere on the board
SPI_1_MISO: U401.6 (SDO), U403.9 (AD0/SDO), U405.9 (AD0/SDO); also elsewhere on the board
SPI_1_MOSI: U401.7 (SDI/SDA), U403.24 (SDA/SDI), U405.24 (SDA/SDI); also elsewhere on the board
SPI_1_SCK: U401.8 (SCLK), U403.23 (SCL/SCLK), U405.23 (SCL/SCLK); also elsewhere on the board
VDD_3V3_SENSORS: C401.P$1 (1), C405.P$2 (2), C406.P$2 (2), C407.P$1 (1), C408.P$1 (1), C410.P$1 (1), C412.P$1 (1), C413.P$1 (1), C414.P$1 (1), C415.P$1 (1), U401.1 (VDD), U403.13 (VDD), U405.1 (NC), U405.8 (VDDIO), U405.13 (VDD), U406.15 (VDD), U406.16 (VDD), U406.17 (VDD), U406.18 (VDD_IO); also elsewhere on the board

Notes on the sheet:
Sensors

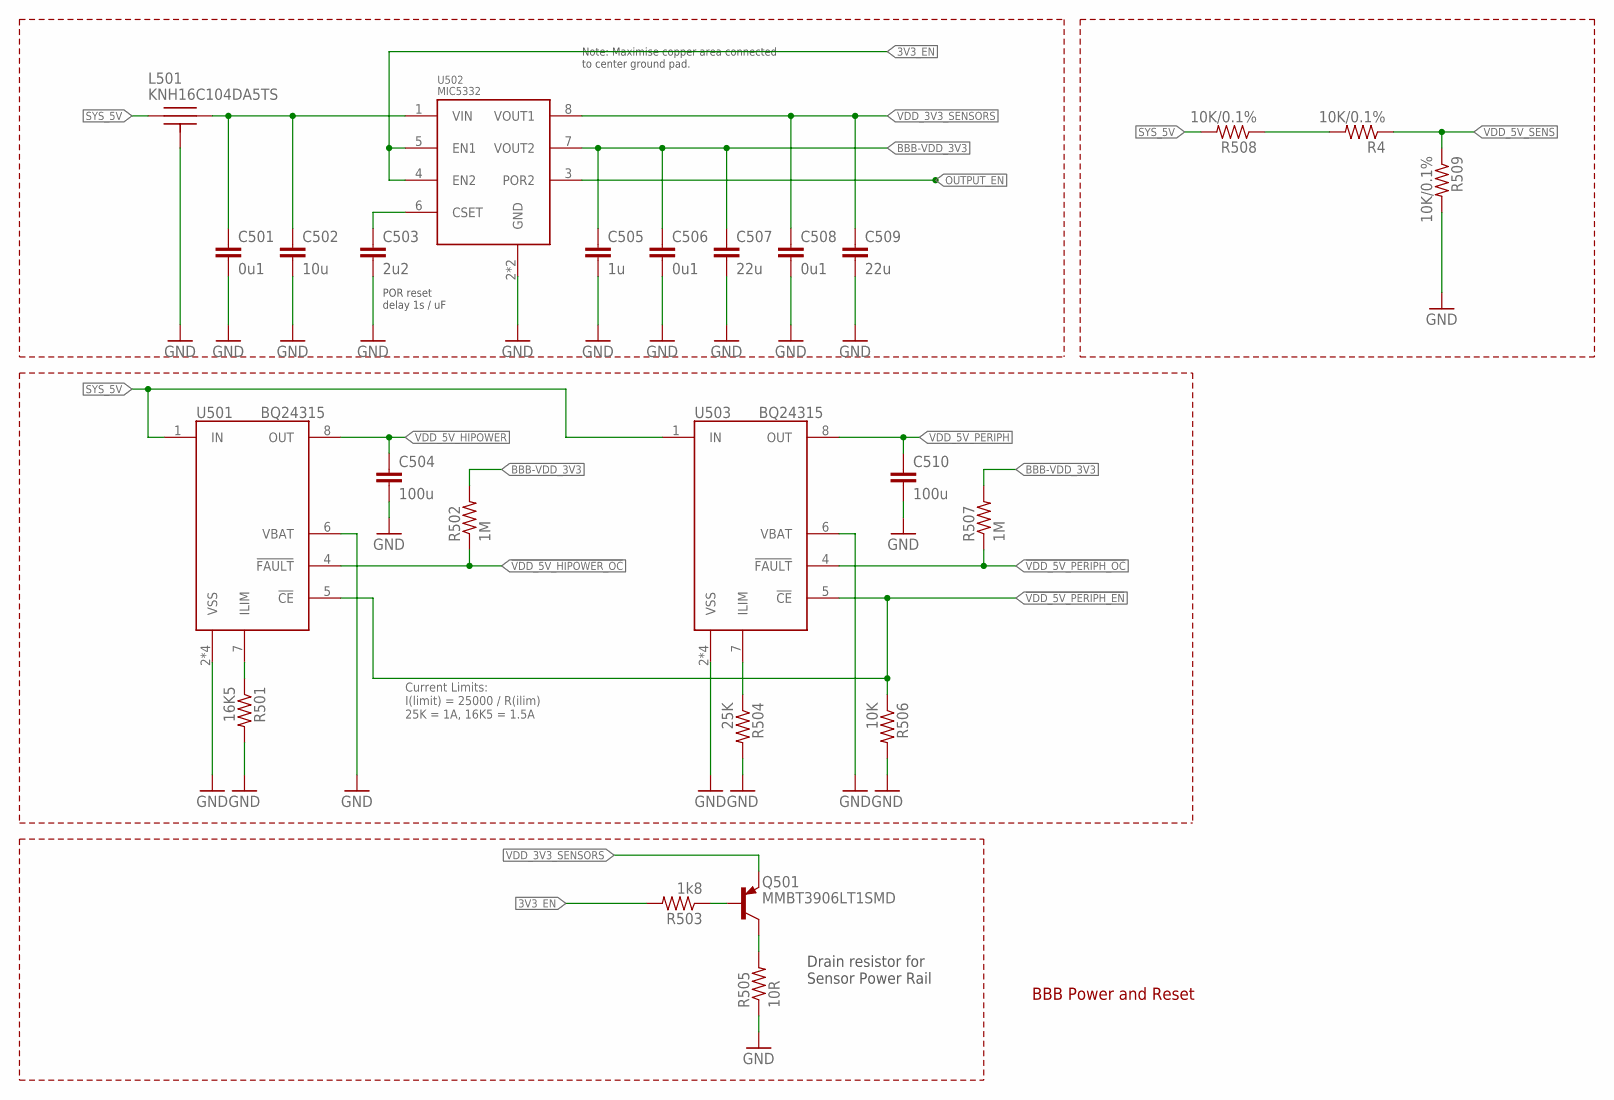
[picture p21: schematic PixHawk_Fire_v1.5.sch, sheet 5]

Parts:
C501, C506, C508: 0u1; 0402-CAP; PARTNO CC0402ZRY5V7BB104
C502: 10u; 0805-CAP; PARTNO C1608X7S0J106M080AC
C503: 2u2; 0603-CAP; PARTNO C1608X6S1C225K080AC
C504, C510: 100u; 1206-CAP; PARTNO C3216X5R1A107M160AC
C505: 1u; 0603-CAP; PARTNO CC0603ZRY5V7BB105
C507, C509: 22u; 0805-CAP; PARTNO CC0805MKX5R5BB226
L501: KNH16C104DA5TS; KYOCERA-KNH16-DA; PARTNO KNH16C104DA5TS
Q501: MMBT3906LT1SMD; SOT23-BEC; PARTNO MMBT3906LT1G
R4, R508, R509: 10K/0.1%; 0402-RES; PARTNO ERA-2AEB103X
R501: 16K5; 0402-RES; PARTNO RMCF0402FT16K5
R502, R507: 1M; 0402-RES; PARTNO MCR01MRTF1004
R503: 1k8; 0402-RES; PARTNO RC0402FR-071K8L
R504: 25K; 0402-RES; PARTNO RMCF0402FT25K5
R505: 10R; 0603-RES; PARTNO RC0402FR-0710RL
R506: 10K; 0402-RES; PARTNO ERA-2AEB103X
U501, U503: BQ24315; QFN8-DSG; PARTNO BQ24315DSGR
U502: MIC5332; MLF-8-EPAD; PARTNO MIC5332-SSYMT

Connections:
3V3_EN: R503.P$2 (2), U502.4 (EN2), U502.5 (EN1); also elsewhere on the board
!VDD_5V_HIPOWER_OC: R502.P$1 (1), U501.4 (!FAULT); also elsewhere on the board
!VDD_5V_PERIPH_EN: R506.P$1 (1), U501.5 (!CE), U503.5 (!CE); also elsewhere on the board
!VDD_5V_PERIPH_OC: R507.P$1 (1), U503.4 (!FAULT); also elsewhere on the board
BBB-VDD_3V3: C505.P$1 (1), C506.P$1 (1), C507.P$1 (1), R502.P$2 (2), R507.P$2 (2), U502.7 (VOUT2); also elsewhere on the board
FMU-VDD_5V5: C501.P$1 (1), C502.P$1 (1), L501.P$2, U502.1 (VIN)
GND: C501.P$2 (2), C502.P$2 (2), C503.P$2 (2), C504.P$2 (2), C505.P$2 (2), C506.P$2 (2), C507.P$2 (2), C508.P$2 (2), C509.P$2 (2), C510.P$2 (2), L501.P$3, L501.P$4, L501.P$5, R501.P$2 (2), R504.P$2 (2), R505.1, R506.P$2 (2), R509.P$2 (2), U501.2 (VSS), U501.6 (VBAT), U501.GND (VSS), U501.P$2 (VSS), U501.P$3 (VSS), U502.2 (GND), U502.GND, U503.2 (VSS), U503.6 (VBAT), U503.GND (VSS), U503.P$2 (VSS), U503.P$3 (VSS); also elsewhere on the board
unnamed: C503.P$1 (1), U502.6 (CSET)
unnamed: R504.P$1 (1), U503.7 (ILIM)
unnamed: R4.P$2 (2), R508.P$1 (1)
unnamed: Q501.C, R505.2
unnamed: Q501.B, R503.P$1 (1)
unnamed: R501.P$1 (1), U501.7 (ILIM)
OUTPUT_EN: U502.3 (POR2); also elsewhere on the board
SYS_5V: L501.P$1, R508.P$2 (2), U501.1 (IN), U503.1 (IN); also elsewhere on the board
VDD_3V3_SENSORS: C508.P$1 (1), C509.P$1 (1), Q501.E, U502.8 (VOUT1); also elsewhere on the board
VDD_5V_HIPOWER: C504.P$1 (1), U501.8 (OUT); also elsewhere on the board
VDD_5V_PERIPH: C510.P$1 (1), U503.8 (OUT); also elsewhere on the board
VDD_5V_SENS: R4.P$1 (1), R509.P$1 (1); also elsewhere on the board

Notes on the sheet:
BBB Power and Reset
Note: Maximise copper area connected to center ground pad.
POR reset delay 1s / uF
Current Limits: I(limit) = 25000 / R(ilim) 25K = 1A, 16K5 = 1.5A
Drain resistor for Sensor Power Rail

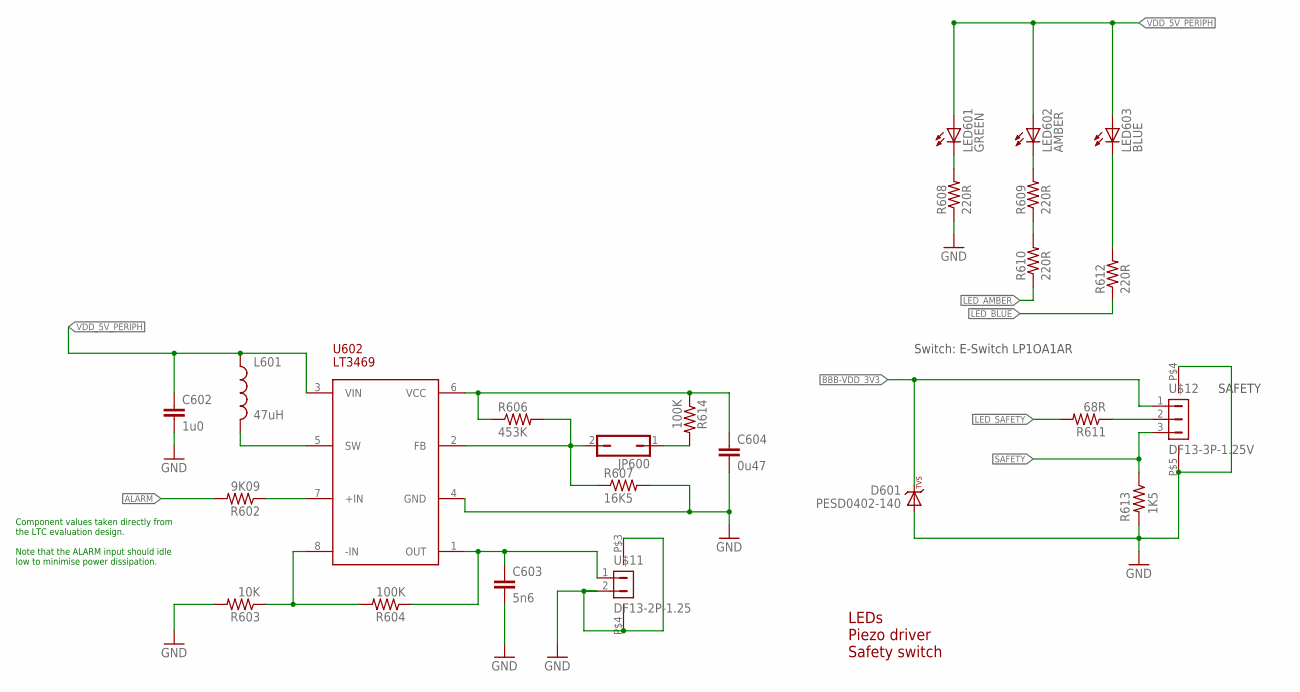
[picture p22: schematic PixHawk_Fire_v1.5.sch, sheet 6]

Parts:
C602: 1u0; 0603-CAP; PARTNO CC0603ZRY5V7BB105
C603: 5n6; 0402-CAP; PARTNO CC0402KRX7R7BB562
C604: 0u47; 0402-CAP; PARTNO C1005X5R1C474K050BC
D601: PESD0402-140; 0402-TVS; PARTNO PESD0402-140
JP600: JP1Q; JP1; PARTNO 1-87215-0
L601: 47uH; 0805-IND; PARTNO MLZ2012M470W
LED601: GREEN; 0603-LED; PARTNO APTD1608CGCK
LED602: AMBER; 0603-LED; PARTNO APTD1608SECK
LED603: BLUE; 0603-LED; PARTNO APTD1608QBC/D
R602: 9K09; 0402-RES; PARTNO RMCF0402FT9K09
R603: 10K; 0402-RES; PARTNO ERA-2AEB103X
R604, R614: 100K; 0402-RES; PARTNO RC0402FR-07100KL
R606: 453K; 0402-RES; PARTNO RMCF0402FT453K
R607: 16K5; 0402-RES; PARTNO RMCF0402FT16K5
R608, R609, R610, R612: 220R; 0402-RES; PARTNO RC0402FR-07220RL
R611: 68R; 0402-RES; PARTNO RC0402FR-0768RL
R613: 1K5; 0402-RES; PARTNO RC0402FR-071K5L
U602: LT3469; SOT23-8; PARTNO LT3469ETS8
U$11: DF13-2P-1.25; DF13C-2P-1.25V; PARTNO DF13C-2P-1.25V(20)
U$12: DF13-3P-1.25V; DF13C-3P-1.25V; PARTNO DF13C-3P-1.25V(20)

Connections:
!LED_AMBER: R610.P$1 (1); also elsewhere on the board
!LED_BLUE: R612.P$1 (1); also elsewhere on the board
!LED_SAFETY: R611.P$2 (2); also elsewhere on the board
ALARM: R602.P$2 (2); also elsewhere on the board
BBB-VDD_3V3: D601.C, U$12.1; also elsewhere on the board
GND: C602.P$2 (2), C603.P$2 (2), C604.P$2 (2), D601.A, R603.P$2 (2), R607.P$2 (2), R608.P$1 (1), R613.P$2 (2), U602.4 (GND), U$11.2, U$11.P$3, U$11.P$4, U$12.P$4, U$12.P$5; also elsewhere on the board
unnamed: LED603.C, R612.P$2 (2)
unnamed: JP600.2, R606.P$2 (2), R607.P$1 (1), U602.2 (FB)
unnamed: R603.P$1 (1), R604.P$2 (2), U602.8 (-IN)
unnamed: C603.P$1 (1), R604.P$1 (1), U602.1 (OUT), U$11.1
unnamed: R602.P$1 (1), U602.7 (+IN)
unnamed: LED601.C, R608.P$2 (2)
unnamed: L601.P$2 (2), U602.5 (SW)
unnamed: C604.P$1 (1), R606.P$1 (1), R614.P$1 (1), U602.6 (VCC)
unnamed: R609.P$1 (1), R610.P$2 (2)
unnamed: LED602.C, R609.P$2 (2)
unnamed: JP600.1, R614.P$2 (2)
unnamed: R611.P$1 (1), U$12.2
SAFETY: R613.P$1 (1), U$12.3; also elsewhere on the board
VDD_5V_PERIPH: C602.P$1 (1), L601.P$1 (1), LED601.A, LED602.A, LED603.A, U602.3 (VIN); also elsewhere on the board

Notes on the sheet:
LEDs Piezo driver Safety switch
Switch: E-Switch LP1OA1AR
SAFETY
Component values taken directly from the LTC evaluation design. Note that the ALARM input should idle low to minimise power dissipation.

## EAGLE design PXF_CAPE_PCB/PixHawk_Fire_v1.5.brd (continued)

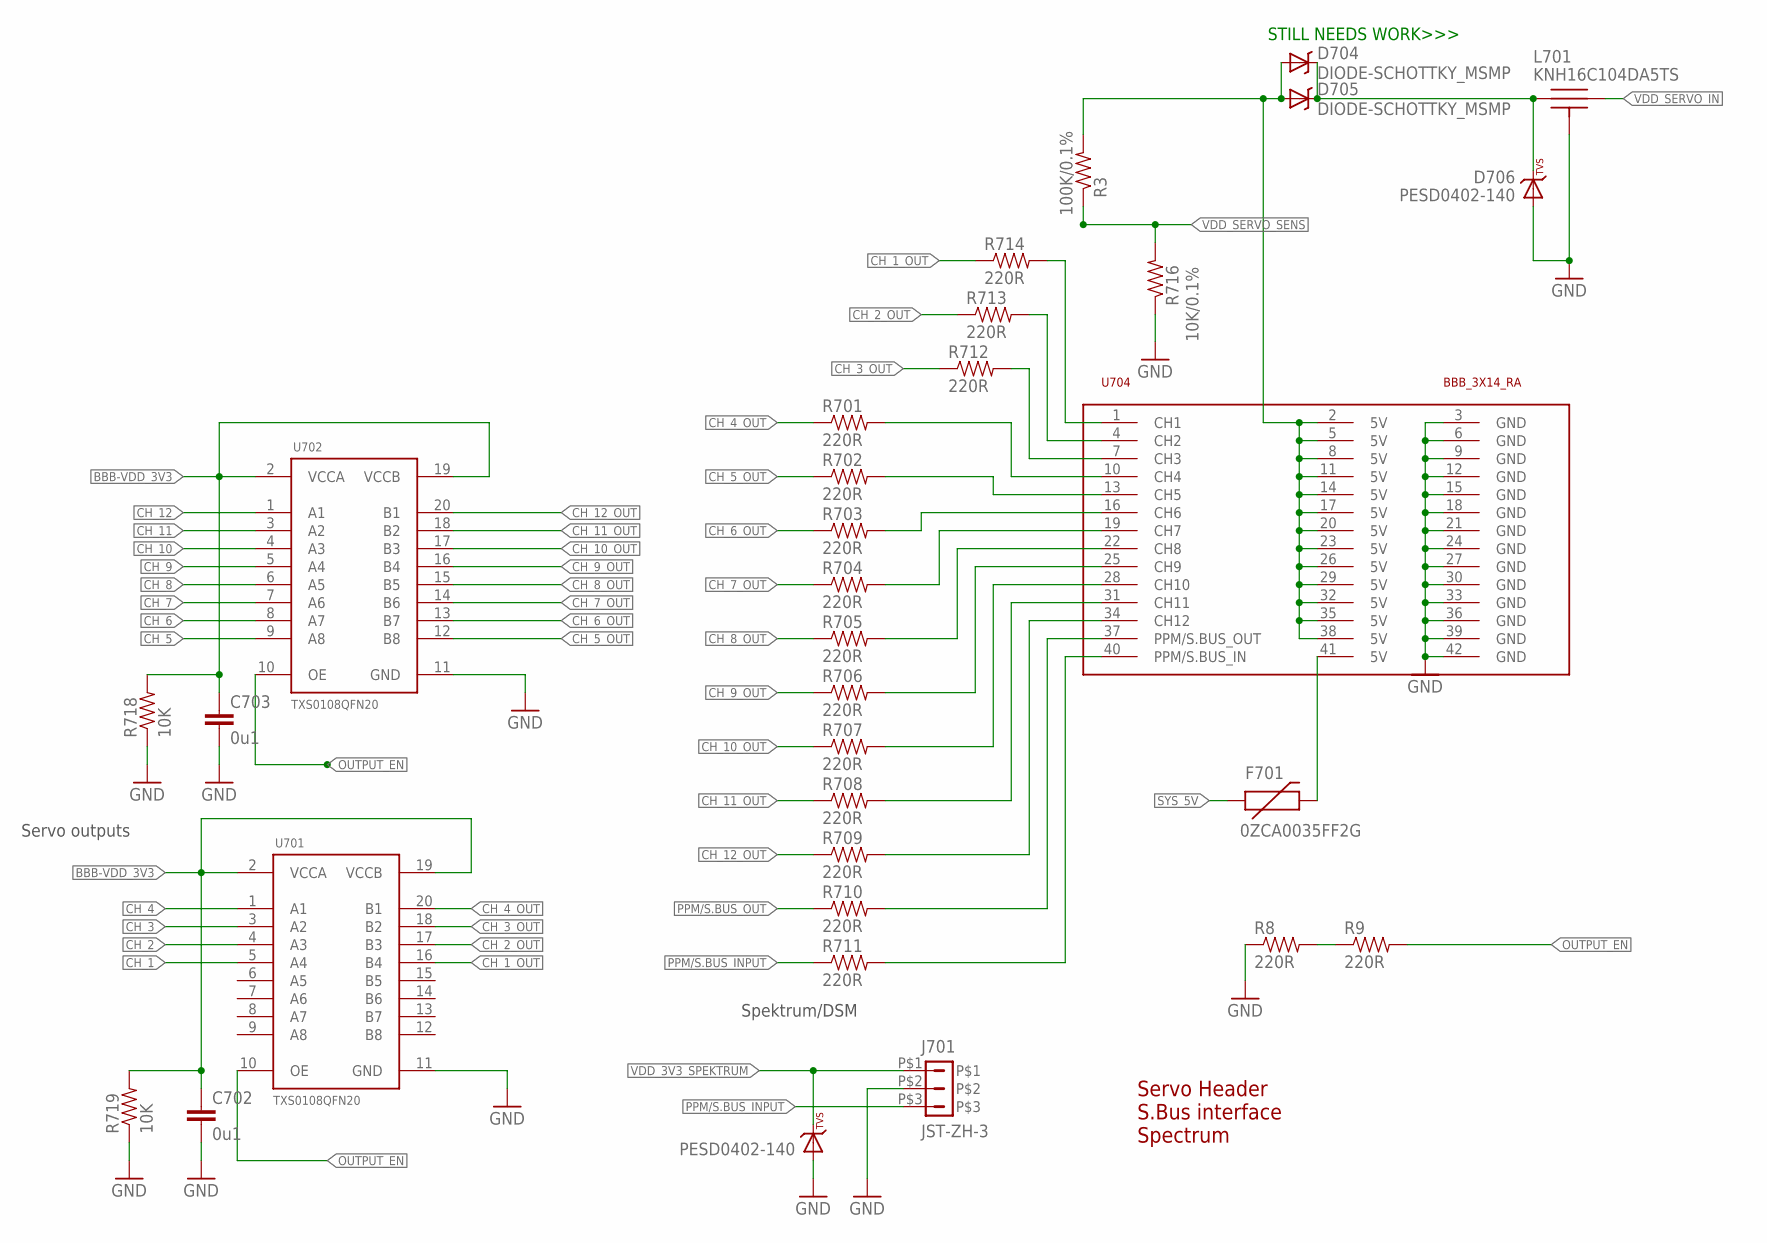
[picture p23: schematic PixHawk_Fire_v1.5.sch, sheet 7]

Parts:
C702, C703: 0u1; 0402-CAP; PARTNO CC0402ZRY5V7BB104
D703, D706: PESD0402-140; 0402-TVS; PARTNO PESD0402-140
D704, D705: DIODE-SCHOTTKY_MSMP; MICROSMP; PARTNO SS14
F701: 0ZCA0035FF2G; PTC-1206; PARTNO 0ZCA0035FF2G
J701: JST-ZH-3; JST-ZH-SMT-VERTICAL; PARTNO B3B-ZR-SM4-TF (LF)(SN)(P)
L701: KNH16C104DA5TS; KYOCERA-KNH16-DA; PARTNO KNH16C104DA5TS
R3: 100K/0.1%; 0402-RES; PARTNO ERA-2AEB104X
R8, R9: 220R; 0402-RES; PARTNO RC0402FR-07220RL
R701, R702, R703, R704, R705, R706, R707, R708, R709, R710, R711, R712, R713, R714: 220R; 0402-RES; PARTNO RC0402FR-07120RL
R716: 10K/0.1%; 0402-RES; PARTNO ERA-2AEB103X
R718, R719: 10K; 0402-RES; PARTNO ERA-2AEB103X
U701, U702: TXS0108QFN20; QFN20-RGY; PARTNO TXS0108ERGYR
U704: BBB_3X14_RA; 3X14RA; PARTNO 07579

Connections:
BBB-VDD_3V3: C702.P$1 (1), C703.P$1 (1), R718.P$2 (2), R719.P$2 (2), U701.2 (VCCA), U701.19 (VCCB), U702.2 (VCCA), U702.19 (VCCB); also elsewhere on the board
CH_1: U701.5 (A4); also elsewhere on the board
CH_1_OUT: R714.P$1 (1), U701.16 (B4)
CH_2: U701.4 (A3); also elsewhere on the board
CH_2_OUT: R713.P$1 (1), U701.17 (B3)
CH_3: U701.3 (A2); also elsewhere on the board
CH_3_OUT: R712.P$1 (1), U701.18 (B2)
CH_4: U701.1 (A1); also elsewhere on the board
CH_4_OUT: R701.P$1 (1), U701.20 (B1)
CH_5: U702.9 (A8); also elsewhere on the board
CH_5_OUT: R702.P$1 (1), U702.12 (B8)
CH_6: U702.8 (A7); also elsewhere on the board
CH_6_OUT: R703.P$1 (1), U702.13 (B7)
CH_7: U702.7 (A6); also elsewhere on the board
CH_7_OUT: R704.P$1 (1), U702.14 (B6)
CH_8: U702.6 (A5); also elsewhere on the board
CH_8_OUT: R705.P$1 (1), U702.15 (B5)
CH_9: U702.5 (A4); also elsewhere on the board
CH_9_OUT: R706.P$1 (1), U702.16 (B4)
CH_10: U702.4 (A3); also elsewhere on the board
CH_10_OUT: R707.P$1 (1), U702.17 (B3)
CH_11: U702.3 (A2); also elsewhere on the board
CH_11_OUT: R708.P$1 (1), U702.18 (B2)
CH_12: U702.1 (A1); also elsewhere on the board
CH_12_OUT: R709.P$1 (1), U702.20 (B1)
FMU-CH6-PROT: R708.P$2 (2), U704.31 (CH11)
GND: C702.P$2 (2), C703.P$2 (2), D703.A, D706.A, J701.P$2, L701.P$3, L701.P$4, L701.P$5, R8.P$1 (1), R716.P$1 (1), R718.P$1 (1), R719.P$1 (1), U701.11 (GND), U702.11 (GND), U704.3 (GND), U704.6 (GND), U704.9 (GND), U704.12 (GND), U704.15 (GND), U704.18 (GND), U704.21 (GND), U704.24 (GND), U704.27 (GND), U704.30 (GND), U704.33 (GND), U704.36 (GND), U704.39 (GND), U704.42 (GND); also elsewhere on the board
IO-CH1-PROT: R707.P$2 (2), U704.28 (CH10)
IO-CH8-PROT: R712.P$2 (2), U704.7 (CH3)
unnamed: R8.P$2 (2), R9.P$1 (1)
unnamed: D704.CATHODE (C), D705.CATHODE (C), D706.C, L701.P$1
unnamed: D704.ANODE (A), D705.ANODE (A), R3.P$2 (2), U704.2 (5V), U704.5 (5V), U704.8 (5V), U704.11 (5V), U704.14 (5V), U704.17 (5V), U704.20 (5V), U704.23 (5V), U704.26 (5V), U704.29 (5V), U704.32 (5V), U704.35 (5V), U704.38 (5V)
unnamed: F701.2, U704.41 (5V)
unnamed: R701.P$2 (2), U704.10 (CH4)
unnamed: R709.P$2 (2), U704.34 (CH12)
unnamed: R702.P$2 (2), U704.13 (CH5)
unnamed: R703.P$2 (2), U704.16 (CH6)
unnamed: R704.P$2 (2), U704.19 (CH7)
unnamed: R705.P$2 (2), U704.22 (CH8)
unnamed: R706.P$2 (2), U704.25 (CH9)
unnamed: R710.P$2 (2), U704.37 (PPM/S.BUS_OUT)
unnamed: R711.P$2 (2), U704.40 (PPM/S.BUS_IN)
unnamed: R713.P$2 (2), U704.4 (CH2)
OUTPUT_EN: R9.P$2 (2), U701.10 (OE), U702.10 (OE); also elsewhere on the board
PPM-SBUS-PROT: R714.P$2 (2), U704.1 (CH1)
PPM/S.BUS_INPUT: J701.P$3, R711.P$1 (1); also elsewhere on the board
PPM/S.BUS_OUT: R710.P$1 (1); also elsewhere on the board
SYS_5V: F701.1; also elsewhere on the board
VDD_3V3_SPEKTRUM: D703.C, J701.P$1; also elsewhere on the board
VDD_SERVO_IN: L701.P$2
VDD_SERVO_SENS: R3.P$1 (1), R716.P$2 (2); also elsewhere on the board

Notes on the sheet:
Servo Header S.Bus interface Spectrum
Servo outputs
Spektrum/DSM
STILL NEEDS WORK>>>

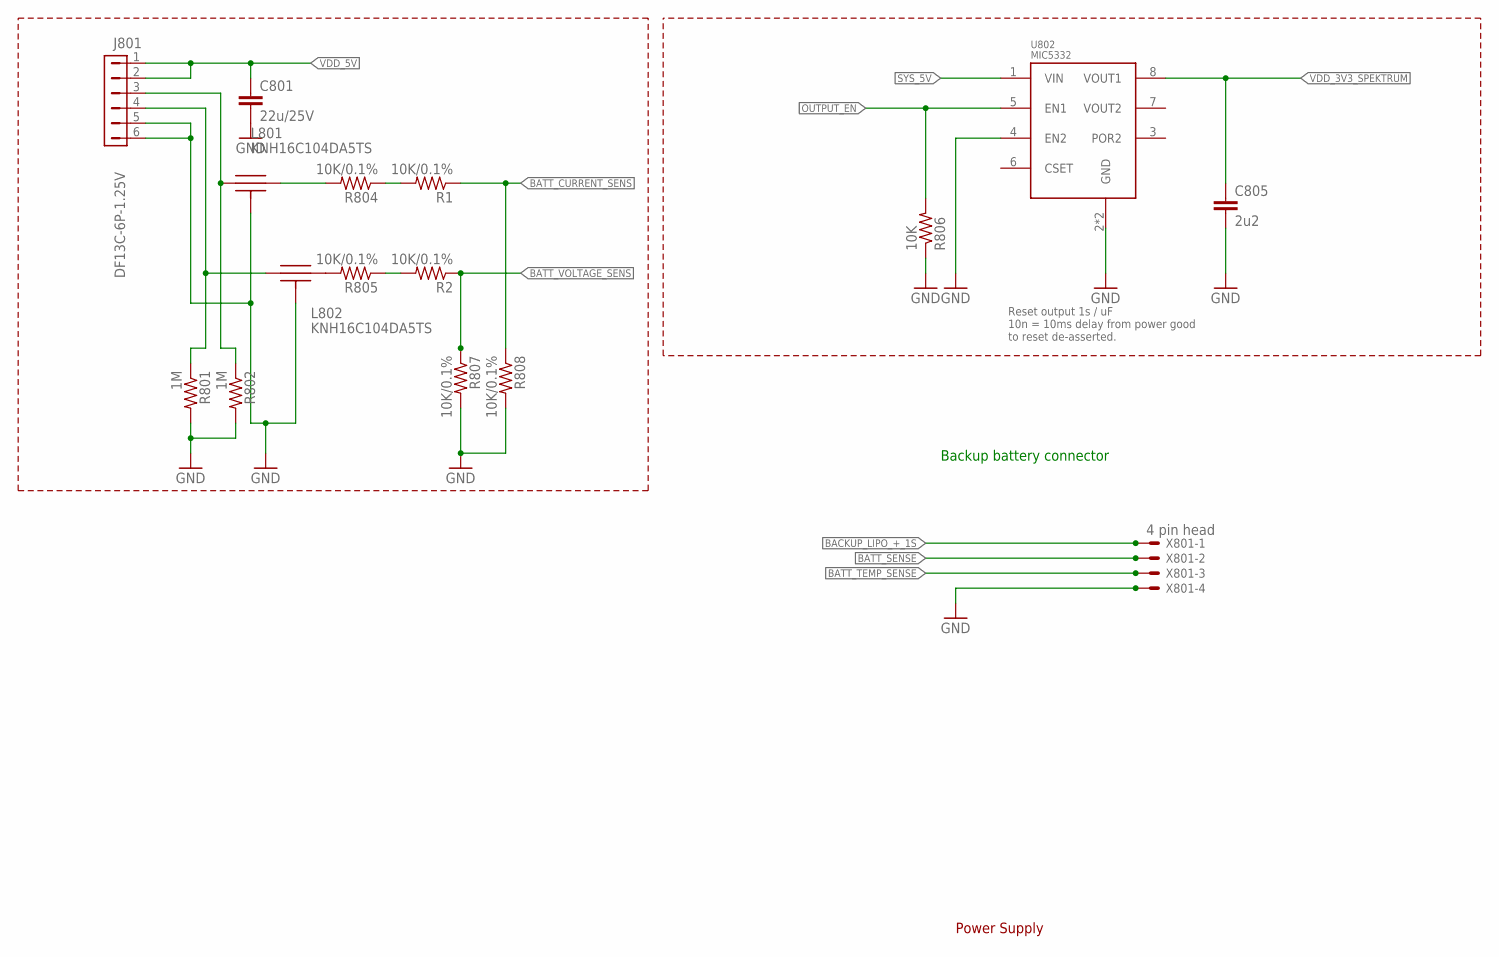
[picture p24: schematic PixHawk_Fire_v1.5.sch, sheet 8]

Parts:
C801: 22u/25V; 0805-CAP; PARTNO CL21A226MAQNNNE
C805: 2u2; 0402-CAP; PARTNO CC0603ZRY5V6BB225
J801: DF13C-6P-1.25V; PARTNO DF13C-6P-1.25V(20)
L801, L802: KNH16C104DA5TS; KYOCERA-KNH16-DA; PARTNO KNH16C104DA5TS
R1, R2, R804, R805, R807, R808: 10K/0.1%; 0402-RES; PARTNO ERA-2AEB103X
R801, R802: 1M; 0402-RES; PARTNO RC0402FR-071ML
R806: 10K; 0402-RES; PARTNO ERA-2AEB103X
U802: MIC5332; MLF-8-EPAD; PARTNO MIC5332-SSYMT
X801: 4 pin head; 53047-04; PARTNO 53047-04

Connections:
BACKUP_LIPO_+_1S: X801.1; also elsewhere on the board
BATT_CURRENT_SENS: R1.P$1 (1), R808.P$1 (1); also elsewhere on the board
BATT_CURRENT_SENS_PROT: J801.3, L801.P$1, R802.P$1 (1)
BATT_SENSE: X801.2; also elsewhere on the board
BATT_TEMP_SENSE: X801.3; also elsewhere on the board
BATT_VOLTAGE_SENS: R2.P$1 (1), R807.P$1 (1); also elsewhere on the board
BATT_VOLTAGE_SENS_PROT: J801.4, L802.P$1, R801.P$1 (1)
GND: C801.P$2 (2), C805.P$2 (2), J801.5, J801.6, L801.P$3, L801.P$4, L801.P$5, L802.P$3, L802.P$4, L802.P$5, R801.P$2 (2), R802.P$2 (2), R806.P$1 (1), R807.P$2 (2), R808.P$2 (2), U802.2 (GND), U802.4 (EN2), U802.GND, X801.4; also elsewhere on the board
unnamed: R1.P$2 (2), R804.P$1 (1)
unnamed: R2.P$2 (2), R805.P$1 (1)
unnamed: L802.P$2, R805.P$2 (2)
unnamed: L801.P$2, R804.P$2 (2)
OUTPUT_EN: R806.P$2 (2), U802.5 (EN1); also elsewhere on the board
SYS_5V: U802.1 (VIN); also elsewhere on the board
VDD_3V3_SPEKTRUM: C805.P$1 (1), U802.8 (VOUT1); also elsewhere on the board
VDD_5V: C801.P$1 (1), J801.1, J801.2; also elsewhere on the board

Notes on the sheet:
Power Supply
Reset output 1s / uF 10n = 10ms delay from power good to reset de-asserted.
Backup battery connector

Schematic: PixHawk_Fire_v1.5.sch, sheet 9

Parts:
ADC_PR: PAD.04; PAD.04X.04; PARTNO *
CAN_H: PAD.04; PAD.04X.04; PARTNO *
CAN_L: PAD.04; PAD.04X.04; PARTNO *
GND, GND.: PAD.04; PAD.04X.04; PARTNO *
JP901, JP902: FIDUCIAL1.5X3; FIDUCIAL-1.5X3; PARTNO *
M3_MOUNT901, M3_MOUNT902, M3_MOUNT903, M3_MOUNT904: MOUNT-HOLE3.1MM; MOUNT-HOLE3.1; PARTNO *
OSHW_LOGO: OSHW-LOGOS; OSHW-LOGO-S; PARTNO *
S1RX, S1TX, S2RX, S2TX: PAD.04; PAD.04X.04; PARTNO *
VDDA_3V901: PAD.04; PAD.04X.04; PARTNO *
VDD_3V901, VDD_5V_BRICK, VDD_5V_IN: PAD.04; PAD.04X.04; PARTNO *

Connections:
BBB-VDD_3V3: VDD_3V901.P$1; also elsewhere on the board
CAN_H: CAN_H.P$1; also elsewhere on the board
CAN_L: CAN_L.P$1; also elsewhere on the board
GND: GND.P$1, GND..P$1; also elsewhere on the board
PRESSURE_SENS_IN: ADC_PR.P$1; also elsewhere on the board
SYS_5V: VDD_5V_IN.P$1; also elsewhere on the board
TTYO4_RX: S1RX.P$1; also elsewhere on the board
TTYO4_TX: S1TX.P$1; also elsewhere on the board
TTYO5_RX: S2RX.P$1; also elsewhere on the board
TTYO5_TX: S2TX.P$1; also elsewhere on the board
VDD_3V3_SENSORS: VDDA_3V901.P$1; also elsewhere on the board
VDD_5V: VDD_5V_BRICK.P$1; also elsewhere on the board

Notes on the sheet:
Mounting holes to suit M3 fastener
and Richco R908 series spacer.
Use R908-5 spacers to stack with
other PX4 series boards (7.95 mm).
Production Testing Pads
Test and Fiducials
Minimum drill: 0.3 mm
Minimum trace width (use mm for traces): 0.15 mm
Minimum copper distance (all signals): 0.15 mm
Dimension / hole minimum distance: 0.2 mm
Layout grid: 4 mil, part grid: 4 mil. Dimensions / hole positions: 0.5 mm
Board: FR4 black, 1.0 mm. Solder stop on vias < 0.6 mm.
Signoff rules: Footprint checked, pinmap checked, schematic checked, cross-references to other pages checked.
Routing: 1: general/escape 2: ground 3: horizontal 4: vertical 5: power 6: general/escape
Fiducials for machine vision alignment.
Parts: Resistors: 0402 / 1% unless specified otherwise Capacitors: 0402 to 1206, ceramic, voltage rating: 10V unless specified

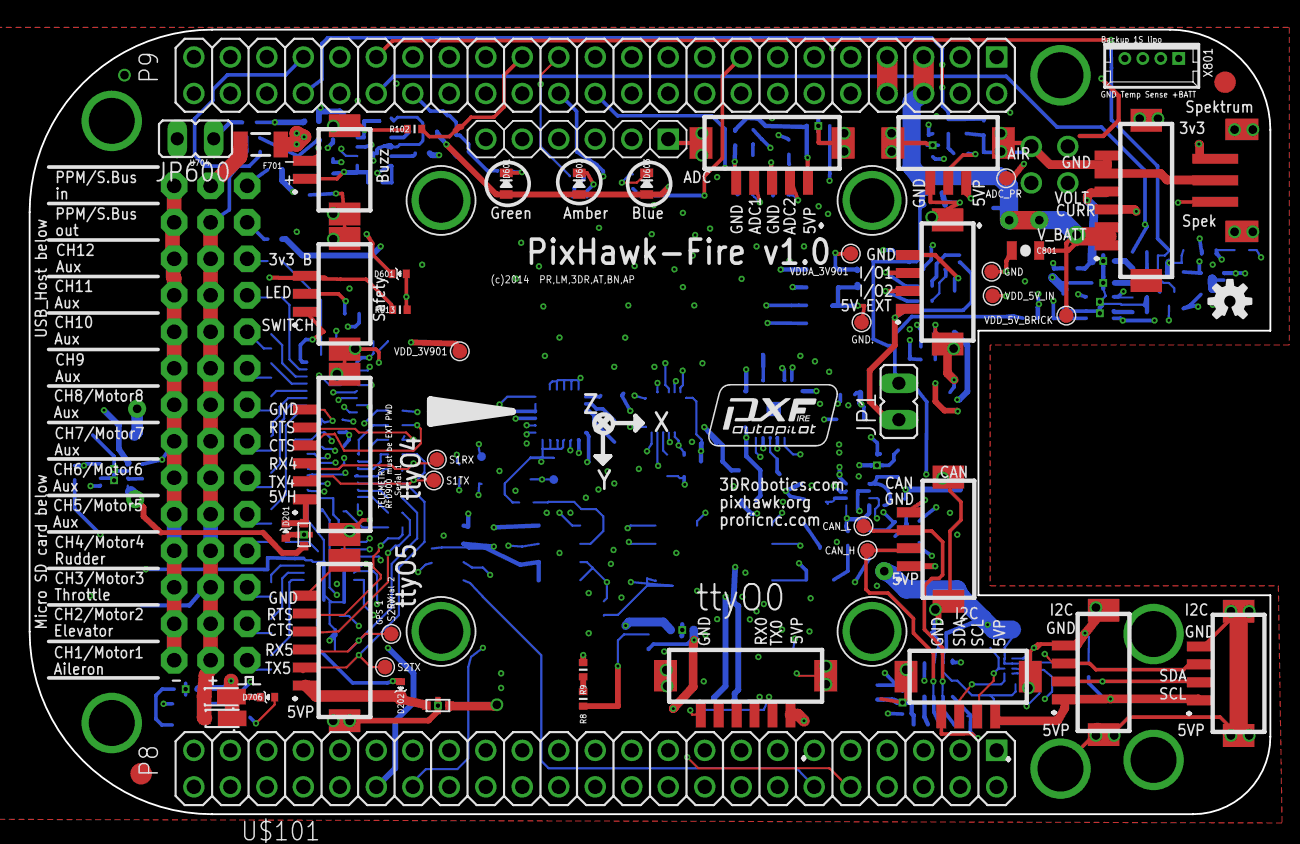
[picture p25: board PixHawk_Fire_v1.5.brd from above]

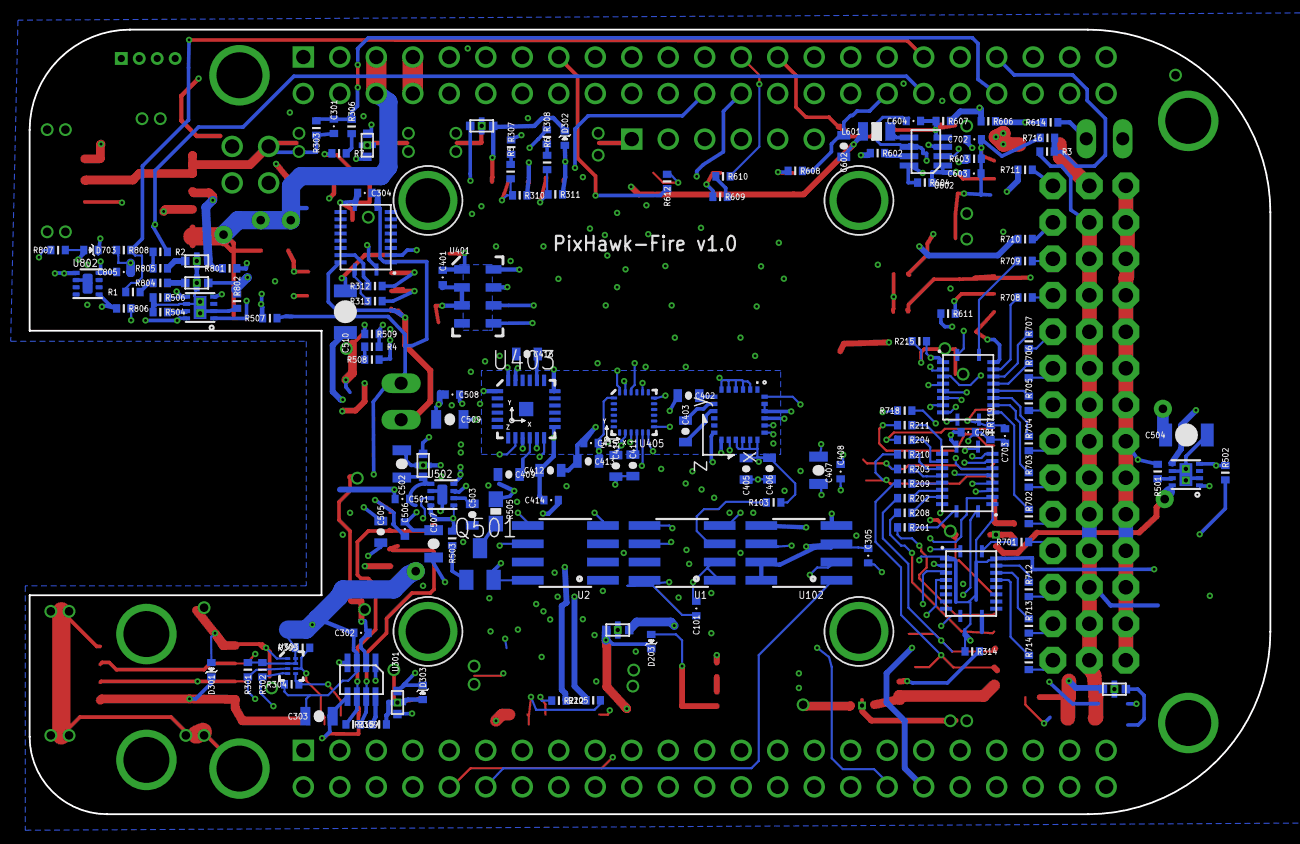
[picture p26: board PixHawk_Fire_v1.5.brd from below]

Board: 6 copper layers, 86.4 x 54.6 mm, 206 parts (149 on the bottom side), 177 nets.

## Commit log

2014-04-27 Added planning doccuments, Schematic, and PCB files
    [CapeRegistration.xlsx, PixHawk_Fire_v1.0.brd, PixHawk_Fire_v1.0.sch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]
2014-04-28 added Device Tree
2014-05-15 maked good sensors with green
    [i2c.xlsx]
2014-05-30 Started v1.1
    [PixHawk_Fire_v1.1.brd, PixHawk_Fire_v1.1.sch]
2014-10-08 Version 1.4, up to date, all fixes merged.
    [PixHawk_Fire_v1.4.brd, PixHawk_Fire_v1.4.sch]
2014-10-09 fixed issue with capacitor on the MPU9250 value was incorrect
2014-10-29 fixed missing ground on Serial 3 plug
    [PixHawk_Fire_v1.4.brd]
2014-11-27 moved to version 1.5 fixed UART BUG
    [PixHawk_Fire_v1.5.brd, PixHawk_Fire_v1.5.sch]

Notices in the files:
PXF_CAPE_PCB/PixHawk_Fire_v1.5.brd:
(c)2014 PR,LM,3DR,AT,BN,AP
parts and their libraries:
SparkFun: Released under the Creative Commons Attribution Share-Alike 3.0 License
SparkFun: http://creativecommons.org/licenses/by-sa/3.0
